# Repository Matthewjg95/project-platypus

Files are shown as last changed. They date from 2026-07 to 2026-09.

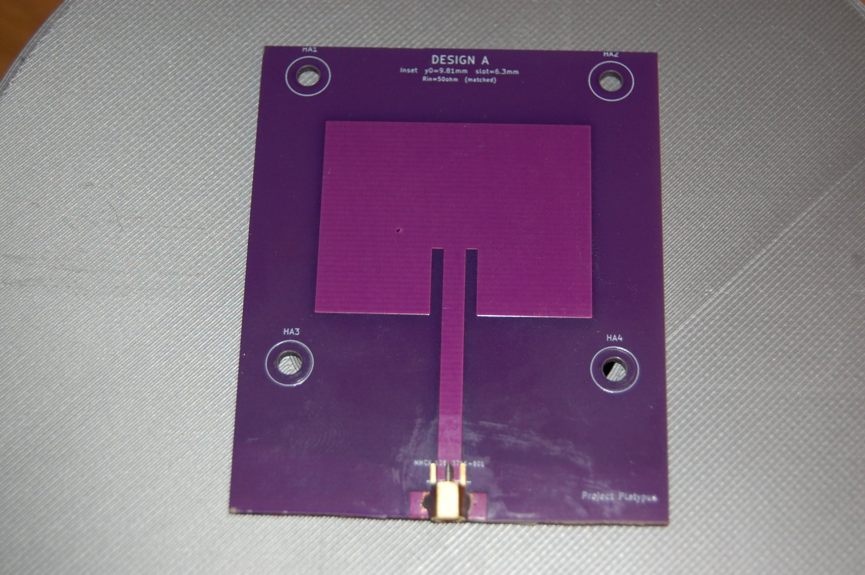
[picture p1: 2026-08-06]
assets/photos/p01_antenna_pcb_designA.jpg

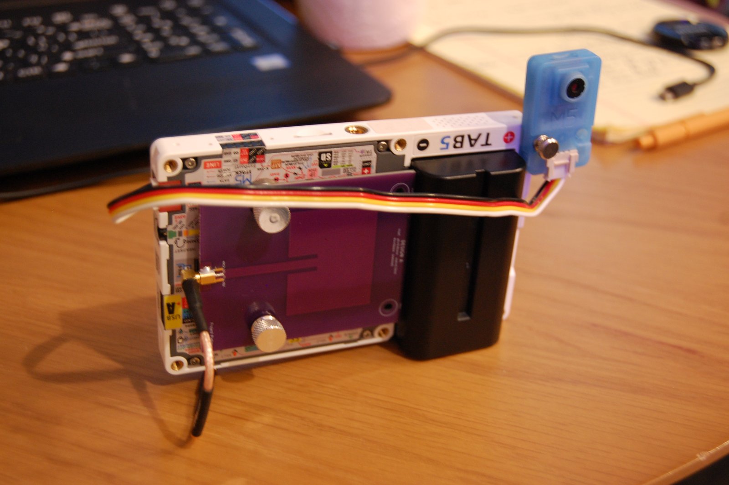
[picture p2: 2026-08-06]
assets/photos/p10_assembled_rig.jpg

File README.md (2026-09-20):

# Project Platypus 🦫

**A self-mapping RF instrument.** An M5Stack **Tab5** with a tethered AI
camera scans a room into a floor plan — then measures the WiFi and paints the
signal onto the map it just drew, one heat layer per antenna, including a
custom patch antenna PCB. No imported floor plans anywhere in the loop: the
instrument draws its own.

> **Status (Sep 2026): submitted to the M5Stack Global Innovation Contest 2026 —
> not selected. This repository is the frozen submission snapshot and is
> archived. Development continues in the lab repo (`platypus-lab`, private),
> which carries the full applet set including ShadowScan.**

Built for the **M5Stack Global Innovation Contest 2026**, as an exercise in
pushing the Tab5 (ESP32-P4) and friends to their limits — and, at roughly
$130 of parts, an accidental RF classroom: aim the patch antenna and watch
directionality appear on the map; swap in an antenna you made and the
instrument tells you if it's better. (The custom antenna boards were $40
for a panel of 45 — the antenna is literally the cheapest part of the
instrument that measures it.)

```
┌─────────────────────────────  M5View shell  ─────────────────────────────┐
│  3D Viewer          Room Scan                    Antenna                 │
│  .mesh renderer     UnitV camera → YOLO →        2.4GHz RSSI scope,      │
│  (orbit/zoom)       carved floor plans,          channel scan, polar     │
│                     WALK+ scans, building map,   plot, INT/EXT switch    │
│                     RF heatmap surveys                                   │
└──────────────────────────────────────────────────────────────────────────┘
        Tab5: ESP32-P4 @360MHz, 1280x720 touch, BMI270 IMU, ESP32-C6 WiFi
        UnitV: Kendryte K210 (KPU NPU), OV7740, MaixPy — tethered via Grove UART
```

## What it does

- **Sweep scan** — stand in a corner, sweep 360°. The BMI270 gyro measures
  the turn (stillness-locked bias calibration, gravity-projected so grip
  doesn't matter); a **sweep dial** fills as you rotate, dropping a colored
  pip at the bearing of every object the camera confirms, and the scan
  finishes itself at a measured full turn. The tethered UnitV streams JPEG +
  YOLOv2 detections over 460800-baud UART; objects are ranged monocularly
  from known real-world sizes (width preferred for wide furniture), passed
  through box sanity gates, and placed by the **median** of their sightings.
- **Visibility-carved floors** — no wall sensor, so the floor is built from
  evidence: where you stood, everything you saw (each sight-line proves open
  floor between you and the object), and everywhere you walked. Rooms come
  out L-shaped when they are L-shaped — not bounding boxes.
- **WALK+** — extend a scanned room on foot. IMU step detection dead-reckons
  your path (drift absorbed by registering against the room's own objects as
  landmarks); the walked path becomes floor-truth for the carve, and —
- **Walk-fused RF survey** — while you walk, the target AP is sampled at
  your pose *and bearing*, so **one walk produces the room and its heatmap**.
  Manual tap-to-sample still works. Heat layers are per-antenna (internal vs
  the custom MMCX patch via the Tab5's RF switch), with a dBm legend and
  automatic DEAD / BEST spot callouts. Because every sample records its aim,
  the directional patch is measured honestly — and its strongest bearing
  draws an "AP this way?" ray. (Ekahau needs an imported floor plan;
  Platypus draws its own.)
- **Additive scanning** — rescanning registers new observations against the
  room's persistent object database (yaw + translation solved from the
  objects themselves) and merges. Rooms improve with every pass; a per-room
  **object menu** toggles anything the model found on/off, and the floor
  re-carves to match.
- **Building map** — every room's carved footprint on one top-down canvas;
  drag rooms to arrange your building, tap to open. Arrangements persist.
- **Live view** — realtime detection viewfinder with class-colored boxes.
- **3D Viewer** — the original mesh renderer (int16 vertices, precomputed
  normals, bucket-sorted painter's algorithm) for `.mesh` files from SD;
  `tools/stl_to_mesh.py` converts STLs.
- **Antenna** — 2.4GHz test bench: a live RSSI oscilloscope and a
  fast-sampling walk test, both driving the internal/external antenna
  switch, with per-antenna running averages and CSV logging to SD.

## Repo layout

```
Tab5 3D Render/          the Tab5 firmware (PlatformIO, Arduino, ESP32-P4)
  src/                   M5View shell + applets (viewer, scanner/, antenna/)
  src/scanner/cv/        portable SfM pipeline for Phase 2 (ORB, RANSAC,
                         essential matrix, triangulation, surface recon)
  docs/                  renderer internals, heatmap design, detection
                         tuning protocol, antenna/WiFi postmortem
  tools/                 stl_to_mesh, screenshots, OTA push, serial log
meshscan/
  unitv/                 UnitV (K210/MaixPy) camera firmware — deploys as a
                         single bundled boot.py
  tools/                 unitv_bundle, unitv_upload, mesh_to_obj, kmodel_info
  shared/                standalone .mesh format spec
docs/                    roadmap docs: ToF wall ranging, RF directionality,
                         custom detection model walkthrough
assets/                  build photos + device screenshots
```

## Building & flashing

**Start here: [docs/BUILD_GUIDE.md](docs/BUILD_GUIDE.md)** — desktop
prerequisites → assembly → camera flash → Tab5 flash → first scan, with a
troubleshooting table. **[docs/CODE_TOUR.md](docs/CODE_TOUR.md)** is a
guided reading order for the source. The short version:

**Tab5** (PlatformIO):
```bash
cd "Tab5 3D Render"
pio run -e tab5 -t upload                 # over USB
pwsh tools/ota_push.ps1                   # over WiFi (device on home screen)
```
- Create `Tab5 3D Render/include/wifi_creds.h` (gitignored) with
  `OTA_WIFI_SSID / OTA_WIFI_PASS / OTA_HOSTNAME` before building.
- OTA arms only on the M5View home screen (green `OTA ready` chip), so it
  never fights the applets that own the radio. 60s watchdog + serial
  heartbeat built in.

**UnitV camera** (MaixPy v0.5.0 on the K210):
```bash
cd meshscan/tools
python unitv_bundle.py                    # bundles modules into one boot.py
python unitv_upload.py ../unitv/build/boot.py /flash/boot.py COM10
```
- The bundle exec-loads every module from RAM at boot (this MaixPy build's
  boot-time filesystem imports are unreliable) and sidesteps SD shadowing.
- Detection model: tiny-YOLOv2 VOC-20 (`meshscan/unitv/model/20class.kmodel`,
  from kendryte-standalone-demo) goes on the camera SD as
  `/sd/20class.kmodel`.

**Debug niceties**
- `python "Tab5 3D Render/tools/tab5_screenshot.py" COM6 out.bmp` — send
  `SS` over USB, get a pixel-perfect 1280x720 framebuffer capture.
- `tools/serial_log.py` — timed telemetry capture (it localized an
  intermittent camera freeze to corrupt bytes arriving on the link — frames
  stalled while CRC errors climbed, receiver healthy throughout, resync
  self-recovering within seconds).
- Serial heartbeat `[hb] up/home/ota/heap` every 5s pinpoints any lockup.

## Hard-won hardware notes (the short list)

- **Tab5 WiFi**: the P4 has no radio — WiFi rides an ESP32-C6 over hosted
  SDIO. Arduino defaults target the P4 EV-board; the Tab5 needs
  `WiFi.setPins(12, 13, 11, 10, 9, 8, 15)` *before* any WiFi call.
- **ArduinoOTA/mDNS must init at most once per boot** on hosted WiFi —
  an end()/begin() cycle hard-froze the loop task.
- **UART RX buffer**: `setRxBufferSize()` is a no-op *after* `begin()`.
  Real-room JPEGs (~8KB) overflowed the default buffer → CRC storm. 32KB,
  set before begin.
- **PI4IOE5V6408 expander (RF switch, 0x43)**: register 0x01 is *Chip
  ID/Control with bit0 = software reset* — writing it blanks the display
  (other rails share the chip). Output register is 0x05; Hi-Z (0x07) must be
  cleared to drive a pin.
- **K210/MaixPy**: `/sd` precedes `/flash` in sys.path (stale SD files shadow
  firmware); boot-time file opens fail intermittently on some files; ampy
  crawls at ~1KB/s — hence the bundler + custom uploader.
- **A directional antenna breaks position-only surveys**: patch RSSI is a
  function of position AND aim (10–15dB front-to-back), so every sample
  records its bearing — omni layers ignore it, the patch layer requires it.

## Roadmap

Measured wall polygons via a ToF ranger on the M5-Bus I2C (the sweep dial
becomes a live floor-plan radar — see `docs/TOF_RANGING.md`), a custom
detection model with door/window classes (`docs/CUSTOM_MODEL_WALKTHROUGH.md`),
Phase-2 SfM walls, an M5-Bus expansion breakout PCB ("Design B": one small
board fans the internal I2C out to Grove jacks — ToF at 0x29, the joystick
at 0x63 whose driver already waits in-tree, and friends), and a printed
enclosure with a peripheral bay + swappable sensor pod to house it all.

---
*Built collaboratively with Claude (Anthropic) driving firmware, debugging,
and tooling over serial — including taking its own screenshots of the device.*

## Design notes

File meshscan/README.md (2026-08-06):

# meshscan/ — UnitV camera firmware + desktop tools

The camera half of Project Platypus. The Tab5 firmware lives in
`Tab5 3D Render/`; this tree holds what runs on the **M5 Unit V (Kendryte
K210)** and the desktop helpers that deploy and inspect it.

| Path | What |
|---|---|
| `unitv/` | MaixPy firmware: OV7740 capture → KPU tiny-YOLOv2 → JPEG + detections streamed over Grove UART (460800) as framed, CRC-8-checked packets |
| `unitv/model/20class.kmodel` | tiny-YOLOv2 VOC-20 (kendryte-standalone-demo), lives on the camera SD as `/sd/20class.kmodel` |
| `tools/unitv_bundle.py` | bundles every module into ONE `boot.py` executed from RAM — this MaixPy build's boot-time filesystem imports are unreliable, and a single file also sidesteps `/sd` shadowing `/flash` |
| `tools/unitv_upload.py` | chunked base64 raw-REPL uploader (ampy crawls and mis-roots relative paths) |
| `tools/unitv_fix_sd_shadow.py` | removes stale SD copies that would shadow flash modules |
| `tools/mesh_to_obj.py`, `tools/kmodel_info.py` | inspect scan output / kmodel headers on the desktop |
| `shared/mesh_format.h` | standalone spec of the `.mesh` binary format |

## Deploy the camera

```bash
cd meshscan/tools
python unitv_bundle.py                                   # -> ../unitv/build/boot.py
python unitv_upload.py ../unitv/build/boot.py /flash/boot.py COM10
```

Wire protocol (camera → Tab5): `FRAME 0xF1 | len u16 | jpeg | crc8` and
`DETECT 0xD1 | frame_id u16 | count u8 | 10B/det | crc8` (CRC-8 poly 0x07).
Config (baud, model path, anchors, thresholds, detect-every-N) lives in
`unitv/config.py`; the camera prints `[det]`/`[tele]` telemetry on its USB
console while the Grove feeds the Tab5.

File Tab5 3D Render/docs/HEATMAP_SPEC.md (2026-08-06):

# RF Survey — WiFi Heatmap on a Self-Scanned Room

> **STATUS: historical design document.** The survey shipped, evolved past
> this spec, and `src/scanner/rf_survey.h/.cpp` is the source of truth. What
> changed since this was written: samples live in the mesh's **int16 model
> space** with the capture quantisation recorded so rebuilds remap them
> (format **RFS4**); every sample records the device **bearing** (the
> external patch antenna's RSSI depends on aim as much as position); INT/EXT
> antennas are separate flippable heat layers with DEAD/BEST callouts and a
> legend; the AP picker is a real UI with a persisted global choice; and
> **WALK+ fuses surveying into walking** — pose-tracked samples collect
> automatically during a walk scan. Kept for the original design rationale.

The Project Platypus fusion feature and contest centerpiece: scan a room into a
3D mesh (Room Scan), then walk the room sampling WiFi RSSI and paint the signal
onto the mesh you just made. Ekahau needs an imported floor plan; Platypus
draws its own.

**MVP = manual sampling** (user taps their position). SfM pose-tracked
auto-positioning is the roadmap version, not the contest version.

---

## 1. User flow (the contest demo path)

```
BROWSE room list ──open──> VIEW (3D mesh)
                              │  new [SURVEY] button
                              v
                           SURVEY
   ┌───────────────────────────────────────────────┐
   │  left 2/3: TOP-DOWN floor plan of the mesh    │
   │    (room footprint + object markers + past    │
   │     samples as colored discs)                 │
   │  right 1/3: live RSSI readout (big number),   │
   │    AP name, antenna INT/EXT toggle,           │
   │    [SAMPLE HERE] button                       │
   └───────────────────────────────────────────────┘
1. First entry: pick target AP (reuse antenna app's scan-and-pick list).
2. Walk somewhere. Tap your location on the floor plan -> crosshair.
3. Press SAMPLE -> 3 quick single-channel scans, averaged -> disc appears,
   colored by dBm. Auto-saves.
4. 8-12 samples in, toggle [HEAT] -> IDW-interpolated floor heatmap renders
   (2D top-down first; 3D floor painting once renderer supports face colors).
5. Optional wow: switch INT->EXT antenna, resample same spots -> two layers,
   compare internal vs MMCX antenna coverage on the same map.
```

Back button: SURVEY -> VIEW -> BROWSE (existing pattern, reset touch state).

## 2. Data model

```cpp
// One measurement at a user-declared position (room/mesh coordinates, metres,
// same frame as the .mesh: floor plane XZ, origin = scan origin).
struct RfSample {
    float   x, z;          // position on floor plane
    int8_t  rssi;          // averaged dBm of the sample burst
    int8_t  rssi_min, rssi_max;
    uint8_t antenna;       // 0=INT 1=EXT
    uint8_t flags;         // reserved
    uint32_t t_ms;         // millis() at capture (session-relative)
};

struct RfSurvey {
    char     ssid[33];
    uint8_t  bssid[6];
    uint8_t  channel;
    uint16_t count;
    RfSample samples[RF_MAX_SAMPLES];   // 256 is plenty; 3.5 KB
};
```

### On-disk: `<room>.rf` next to `<room>.mesh`
`/meshscan/buildings/<b>/<room>.rf`, little-endian:

```
magic  "RFS1"            4 bytes
ssid   char[33]          NUL-padded
bssid  u8[6]
chan   u8
count  u16
samples: count * 16 bytes  (f32 x, f32 z, i8 rssi, i8 min, i8 max,
                            u8 antenna, u8 flags, u8 pad, u16 pad)
```

Load on entering SURVEY if present; append + rewrite on each sample (file is
tiny, no chunking needed). Delete room -> delete .rf too (project_manager).

## 3. WiFi sampling (scanner side)

Reuse the antenna app's proven recipe, minimally:

```cpp
WiFi.setPins(12, 13, 11, 10, 9, 8, 15);   // Tab5 C6 - once, before mode()
WiFi.mode(WIFI_STA);
// AP pick: full scanNetworks() once, user taps AP (strongest preselected).
// Per sample: 3x single-channel scan (WiFi.scanNetworks(false,false,false,
// SCAN_DWELL, channel)), match BSSID, average RSSI. ~300-500 ms total.
```

- Sampling happens ONLY in SURVEY state (no background scanning; UART/scan
  pipeline untouched).
- INT/EXT toggle drives the RF switch exactly as the antenna applet does
  (`M5.In_I2C` expander write, 1 s settle before sampling).
- Coexistence note: WiFi (C6 SDIO) + SD + UART camera feed have all run
  together already; survey does not use the camera, so no new contention.

## 4. Rendering

### 4a. Top-down floor plan (MVP, pure 2D — ships first)
- Orthographic projection of mesh bounds onto XZ: `px = (x-xmin)/(xmax-xmin)*W`.
- Draw: room rectangle, object markers (from scan's acc list / .mesh objects)
  as small labeled squares, samples as filled discs (r=8) in the dBm color.
- Crosshair at pending tap position.

### 4b. Color scale (shared)
```
>= -55 dBm  green   0x07E0      -70..-80  orange  0xFC00
 -55..-70   yellow  0xFFE0      < -80     red     0xF800
no data     dark grey grid
```

### 4c. Heatmap interpolation (MVP)
Inverse-distance weighting over a coarse floor grid:
- Grid: 32 x 24 cells over mesh XZ bounds (fits any room aspect).
- `value(cell) = sum(w_i * rssi_i) / sum(w_i)`, `w_i = 1/(d_i^2 + eps)`;
  cells farther than ~2.5 m from every sample render as "no data".
- 32*24*~10 samples = trivial compute; recompute on each new sample.
- 2D view: fillRect per cell at 60% opacity feel (blend by drawing the grid
  first, discs/objects on top).

### 4d. 3D floor painting (stretch, after 2D works)
One contained renderer extension unlocks this AND Phase-2 colored geometry:

```cpp
struct Mesh {
    ...
    uint16_t* face_colors = nullptr;   // optional; RGB565 per face
};
// renderer.h: color = mesh.face_colors ? tint(face_colors[i], shade)
//                                      : _shade_color(rn);
```

Then SURVEY builds a floor-grid sub-mesh (2 triangles per cell, y=0.01) with
`face_colors` from the IDW grid and appends it to the room mesh for the 3D
view. Billboard-free, no new draw path.

## 5. Code layout

```
src/scanner/rf_survey.h/.cpp   RfSurvey store, .rf IO, IDW grid, color scale
src/scanner/scanner_applet.h   + SURVEY state: touch handling, 2D draw,
                               sample flow, AP picker (modeled on antenna's)
src/renderer.h                 + optional face_colors (stretch item 4d)
```

Keep rf_survey.* free of display calls (testable), scanner_applet owns UI —
same split as the rest of the scanner.

## 6. Effort plan

| Step | Scope | Est |
|---|---|-----|
| 1 | rf_survey store + .rf IO + color scale | 0.5 d |
| 2 | SURVEY state: top-down view, tap, crosshair | 1 d |
| 3 | WiFi sample burst + AP picker | 0.5 d |
| 4 | IDW grid + 2D heat overlay | 0.5 d |
| 5 | INT/EXT dual-layer surveys | 0.5 d |
| 6 | (stretch) face_colors renderer + 3D floor paint | 1 d |

MVP (1-5) ≈ 3 days of focused work; contest-demoable after step 4.

## 7. Roadmap (post-contest)
- SfM pose-tracked sampling: Phase-2 pipeline already estimates camera pose;
  tag RSSI to live pose while walking -> dense heatmap, no tapping.
- Multi-AP surveys (store N surveys per room, switch layers).
- Channel-congestion overlay (antenna app's channel scanner data on the map).
- Export: .rf -> CSV/PNG via a desktop tool in meshscan/tools/.
```

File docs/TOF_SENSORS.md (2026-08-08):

# Time-of-Flight Sensors — How They Actually Work

Research companion to `TOF_RANGING.md` (which covers our integration plan).
This is the physics and engineering background for the VL53L1X that's about
to join the instrument — what it measures, how, and where it lies.

---

## 1. The core idea, and why it's hard

Light travels ~30cm per nanosecond. Measure how long a photon takes to fly
to a wall and back, halve it, multiply by c: that's your distance. The
problem is the timescale — a millimetre of range resolution corresponds to
**~6.7 picoseconds** of round-trip time. No $5 chip times a single photon
that precisely. Every practical ToF sensor is a clever workaround for that
fact, and the workarounds split into two families.

## 2. Direct ToF (dToF) — what the VL53 family is

Direct ToF really does time photon flights — it just does it *statistically*.

1. A **VCSEL** (vertical-cavity surface-emitting laser, 940nm, Class 1
   eye-safe) fires thousands of sub-nanosecond pulses.
2. The receiver is a **SPAD array** (single-photon avalanche diodes) —
   pixels so sensitive that ONE returning photon triggers a detectable
   avalanche. The VL53L1X has a 16×16 SPAD array behind a lens.
3. Each detection is time-stamped by a TDC (time-to-digital converter) and
   dropped into a **histogram** of arrival times.
4. After thousands of pulses, the histogram shows a peak: ambient photons
   arrive uniformly at random (a flat floor), while photons that bounced
   off your wall pile up at one specific round-trip time. Find the peak,
   read the distance.

This histogram trick is why dToF has properties that matter for us:

- **Range accuracy is mostly independent of target brightness.** A dark
  wall returns fewer photons → shorter max range and a noisier peak, but
  the peak's *position* (= distance) doesn't shift. Intensity-based sensors
  can't say that.
- **Ambient light raises the histogram's noise floor** rather than biasing
  the answer — sunlight (which contains plenty of 940nm) shortens usable
  range but degrades gracefully.
- **Multiple returns are visible in principle** — glass edge + wall behind
  it produce two peaks. (The VL53L1X reports the strongest; fancier lidars
  report several.)

## 3. Indirect ToF (iToF) — the other family, for contrast

Instead of pulses, iToF emits **continuously modulated** light (tens of
MHz) and measures the **phase shift** between emitted and received
waveforms — phase maps to distance. It's how most depth *cameras* work
(phone depth sensors, Kinect-era devices): cheap per-pixel, whole images at
once. The catch: phase wraps around every c/(2·f_mod) metres, creating
distance ambiguity that needs multi-frequency tricks, and accuracy depends
on signal strength. For single-point ranging, dToF won this market — which
is why the part we're using is dToF.

## 4. The VL53L1X specifically

| Property | Value | What it means for Platypus |
|---|---|---|
| Principle | dToF, SPAD histogram | reflectance-tolerant wall ranges |
| Emitter | 940nm VCSEL, Class 1 | invisible, eye-safe, indoor-friendly |
| Max range | ~4m (long mode, low ambient) | covers a room from its centre |
| Min range | ~4cm | never an issue for walls |
| FoV | ~27° cone, lens-defined | see §5 — the big caveat |
| ROI | programmable 4×4…16×16 SPADs | narrows FoV to ~15°, steerable! |
| Timing budget | 20–1000ms per reading | precision/speed dial (§6) |
| Distance modes | short / medium / long | short = best ambient immunity, ~1.3m cap |
| Typical σ | mm-level near, cm-level far | good enough to beat our carve cells |
| Interface | I2C @ 0x29, interrupt pin | rides the Tab5's M5-Bus internal I2C |

The **ROI feature deserves attention**: you can tell the chip which SPAD
sub-array to use, which both narrows the cone *and steers it slightly*
(±~5°) without moving anything. A future trick: three interleaved ROIs
(left/centre/right) per bearing = a crude 3-zone scanning lidar from one
static part.

## 5. Failure modes — where ToF lies to you

Ranked by how much each will bite the wall-ranging use case:

1. **The cone problem (biggest).** 27° at 3m is a ~1.4m-wide footprint.
   The sensor reports (roughly) the nearest strong return in that cone —
   a chair 1m away wins over the wall 3m away. Mitigations: narrow ROI,
   mount high aiming slightly up (over furniture), and fuse with the
   camera's object map (we KNOW where the chair is — reject ranges that
   match known objects and keep the far return for walls).
2. **Specular surfaces.** A glossy wall, window, or mirror at a non-normal
   angle reflects the beam *away* — few photons return; you get max-range
   noise or a wrong bounce path (mirror shows the reflected room!). Matte
   drywall is ideal; glass walls will be our enemy. Detectable partially
   via signal-rate + range-status flags.
3. **Dark absorptive targets.** Black felt curtains at 4m may simply not
   return enough photons in long mode. Shows up as status "signal fail" —
   filterable.
4. **Ambient IR.** Direct sunlight through a window floods 940nm.
   Short-distance mode is the most immune; expect degraded range near
   bright windows, fine everywhere else indoors.
5. **Crosstalk / cover glass.** Photons bouncing off a window in front of
   the sensor create a false near peak. ST provides a crosstalk
   calibration; our enclosure should leave the sensor aperture OPEN or use
   the calibration if we glaze it.
6. **Wraparound.** Beyond-max-range targets can alias into short readings
   (status flag 7). Filter by status, always.

**The golden rule: never use a bare distance.** The chip reports range
status and signal/sigma estimates with every reading — a trustworthy
pipeline filters on status==0 and feeds sigma into the per-bin median we
already planned (TOF_RANGING.md).

## 6. The precision/speed dial

Timing budget = how long the chip accumulates histogram photons:

- 20ms budget → ~±5mm σ short range, weaker at distance, 50Hz possible
- 33–50ms → the sweet spot for a sweeping scan: 20–30Hz, cm-class at 3m
- 200ms+ → mm-class but far too slow for a rotating sweep

Our sweep math (TOF_RANGING.md): even 20Hz gives a reading every ~0.5° of
rotation — 72 five-degree wall bins get ~10 readings each for medians.
Plan: **medium distance mode, 33ms budget, ~25Hz**, ROI narrowed to
~15–20°, status-filtered, per-bin median. Revisit after bench tests.

## 7. Why ToF beats the alternatives for this job

| Tech | Why not |
|---|---|
| Ultrasonic (HC-SR04) | huge beam lobe (~30°+), slow (~50ms of sound flight), echo multipath in corners, cm accuracy at best |
| IR triangulation (Sharp GP2Y) | ~1.5m max, analog drift, beam still wide |
| Spinning lidar (RPLIDAR etc.) | actually ideal data — but $100+, large, a motor to power and mount; philosophically a different instrument |
| Stereo / structured light | serious compute + calibration; the P4 is busy |
| **dToF (VL53L1X)** | $9, 4m, mm–cm σ, I2C, no moving parts, and our sweep IS the scan motor — the user's rotation replaces the lidar spindle |

That last cell is the design insight: a spinning lidar is a ToF sensor
plus a motor. **Platypus already has the motor — it's the person.** The
sweep dial turns a $9 static ranger into a polar scanner.

## 8. What this means for the firmware (when the part arrives)

1. `tof_ranger.h` — init (distance mode, budget, ROI), poll, and a
   `Reading { mm, sigma_mm, status }` struct. Portable; nothing but I2C.
2. Scan loop: tag readings with IMU yaw; keep status==0; 72-bin medians.
3. **Fusion pass**: reject wall candidates that coincide with known camera
   objects (the cone problem, solved by the sensor we already have).
4. `.wall` sidecar + carve upgrade: measured polygon replaces/augments the
   visibility carve; sight-line evidence still fills where ToF was blocked.
5. Sweep dial: draw the wall trace live — the dial becomes a radar.

---
*Sources: ST VL53L1X datasheet & UM2356 API docs, ST FlightSense appnotes
(histogram dToF architecture), general SPAD/TDC literature. Bench-verify
timing-budget/σ numbers on our unit before trusting them in the pipeline.*

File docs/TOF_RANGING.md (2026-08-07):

# ToF Wall Ranging — Research & Integration Plan

> **STATUS (2026-08-01): post-contest revision.** ToF hardware + custom
> enclosure are roadmapped for after the Aug 7 contest deadline. Until then
> the camera-only path carries layout: visibility-carved floors (occupancy
> union of origin + objects + sight-lines) replaced the rectangular plate.

**Goal:** during the same 360° sweep-dial scan, sample a real distance at every
bearing → the scan produces the room's **actual measured wall outline** (a polar
polygon) instead of a bounding plate inferred from object extents. Objects from
the camera land inside it; the RF heatmap paints onto true room geometry.

This is the single biggest layout upgrade available: rotation-only sweeps give
the camera zero parallax (no depth from motion is possible), and the K210 only
emits 2D boxes — but a ToF ranger measures distance directly.

---

## Hardware findings (researched 2026-08-01)

### The bus problem is solved — no Grove conflict

The Unit V camera owns the Grove port's pins (G53/G54) as UART, and the U006
hub is a passive splitter — UART + I2C can never share those pins. But the
Tab5's **M5-Bus 30-pin header exposes the internal I2C bus directly**:

| M5-Bus pin | Signal |
|---|---|
| SDA | **G31** |
| SCL | **G32** |
| 5V / 3V3 / GND | power |

G31/G32 is the same bus as the BMI270 IMU, RTC, touch, audio codec, and the
PI4IOE5V6408 expanders (0x43/0x44) — i.e. **`M5.In_I2C`, the exact API the
antenna applet already uses**. Proven code path, zero new drivers to bring up.

Address check — internal bus occupants: 0x10, 0x14/0x55, 0x32, 0x40, 0x41,
0x43, 0x44, 0x68. The ToF's **0x29 is free**. Traffic check: M5Unified
serializes In_I2C transactions; a 20–30 Hz ToF poll is light next to touch+IMU.

### Sensor choice

| Unit | Sensor | Range | Notes |
|---|---|---|---|
| **Unit ToF4M (recommended)** | VL53L1X | 4 mm – 4 m | ~30–50 ms/reading, I2C 0x29, ~27° FoV (narrowable to ~15° via ROI) |
| Unit ToF | VL53L0X | up to 2 m | cheaper, but 2 m is too short for wall ranging across a room |
| Mini ToF 90° | VL53L0CXV0DH | 2 m | right-angle form factor — interesting for the enclosure, same 2 m limit |

**ToF4M** it is: 4 m covers typical rooms from the center; 0x29 on In_I2C.

### Wiring

Grove pigtail (Grove-to-Dupont cable, ~$2) from the ToF4M onto the M5-Bus
header: 5V, GND, SDA→G31, SCL→G32. Grove I2C logic is 3.3 V — matches the
internal bus. The enclosure routes/strains this cable.

### BOM

- M5Stack Unit ToF4M (VL53L1X) — ~$9
- Grove-to-Dupont conversion cable — ~$2
- (already owned) Unit V camera on the Grove port, unchanged

---

## Sampling math — it fits the sweep perfectly

A sweep takes ~20–60 s over 360°. At a conservative 20 Hz ToF poll:

- 20–60 s × 20 Hz = **400–1200 range samples per sweep**
- one reading every **0.3–0.9° of rotation** — massively oversampled for a
  wall outline binned at 5° (72 bearings)

Pipeline per sweep: tag each reading with the IMU yaw at capture → bin into 72
bearings → **median per bin** (same robustness philosophy as object ranging) →
polar polygon.

Refinements after the raw polygon works:
1. Split-and-merge line fitting → straight wall segments from the polygon
2. Optional Manhattan snap (90° corners) using the Hough confidence we
   already compute in RoomFitter
3. Corner extraction → the "face a corner" origin convention becomes a
   *measured* anchor, which also gives rescan registration a hard landmark

The 27° sensor cone slightly rounds corners (reads the nearest surface in the
cone); VL53L1X ROI configuration can narrow it to ~15° if that matters.

### Portability note (standing principle)

The wall-ranging pipeline consumes `(yaw_rad, distance_m)` pairs — nothing
else. Any ranger (I2C ToF, UART lidar module, ultrasonic) that produces those
pairs slots in behind the same interface. Keep the sensor driver ~40 lines and
isolated in `src/scanner/tof_ranger.h`.

---

## Beyond the ToF: the M5-Bus as an expansion backbone

The ToF finding generalizes. The camera owns the Grove port's pins as UART —
but the M5-Bus header exposes the **internal I2C bus (SDA G31 / SCL G32)**,
and I2C is a *bus*: every additional I2C peripheral shares those two pins,
distinguished by address. Current occupants: 0x10, 0x14/0x55, 0x32, 0x40,
0x41, 0x43, 0x44, 0x68. That leaves room for:

| Peripheral | Address | Status |
|---|---|---|
| ToF ranger (VL53L1X) | 0x29 | free — this doc's plan |
| M5 Joystick unit | 0x63 | free — **the driver already sits in-tree**
  (`src/joystick_input.h`), disabled since the joystick was unplugged from
  the camera's UART pins; it wires straight back up here |
| Any Grove I2C unit (env sensors, encoders, …) | varies | check the map |

The M5-Bus also carries SPI, UART0, RS485, and ~13 free GPIOs for
peripherals that aren't I2C.

**The physical layer — "Design B":** Grove pigtails onto header pins work
for one device but not for a rig. The clean answer is a small custom
breakout PCB — M5-Bus header in, 3-4 Grove (HY2.0-4P) jacks out, all
sharing the internal I2C + power. The antenna fab run cost $40 for 45
boards; an expansion breakout is the same order of trivial. One board turns
the Tab5's back into a proper peripheral bay — which is exactly what the
enclosure below should assume.

## Enclosure (next phase)

Once camera + ToF + Tab5 travel together, a 3D-printed bracket becomes the
right move:

- **Rigid co-aim is the whole game:** ToF and camera optical axes parallel,
  both normal to the Tab5 back. A fixed yaw offset between them is fine —
  one constant in software — but it must not flex scan-to-scan.
- Back-shell clamshell around the Tab5 with a sensor pod top-center:
  Unit V + ToF4M side by side, Grove cable channel to the port, pigtail
  channel to the M5-Bus header (header access must stay open).
- Keep the power button, USB-C, speaker grille, and antenna connectors clear;
  leave the kickstand/hand-strap question for the design session.
- Stretch: the pod prints as a separate swappable module — future sensors
  (lidar, better camera) get a new pod, not a new shell. Matches the
  modularity principle.

---

## Integration order (when the ToF4M arrives)

1. `tof_ranger.h`: VL53L1X init + poll on `M5.In_I2C` (0x29), ~40 lines
2. Scan loop: sample (yaw, mm) at poll rate during SCAN; store 72-bin medians
3. `.wall` sidecar beside the mesh (bearing/distance table, "WAL1")
4. Mesh: replace the rectangular plate with the measured floor polygon +
   optional low wall ribs at the polygon edges
5. Sweep dial: draw the wall trace ON the ring as it's measured — the dial
   literally becomes a live floor-plan radar (contest demo gold)
6. RF survey: heatmap clipped/painted onto the measured polygon

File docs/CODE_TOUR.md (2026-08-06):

# Code Tour — a guided reading order

The codebase is written to be read: headers open with a purpose block
explaining *why* the module exists, and hard-won lessons are documented at
the line where they were learned (search the source for `HISTORY`,
`LIFECYCLE RULE`, `hard-learned`, `field report` — the comments carry the
war stories). This tour orders the reading so each file makes sense by the
time you reach it.

One honest caveat up front: most modules are small and single-purpose, but
`scanner_applet.h` is the orchestrator and it is *large* (~2,500 lines). It
is organized by scan-screen state; the section map below is your index into
it.

## The 30-second architecture

```
 Unit V camera (K210, MaixPy)                Tab5 (ESP32-P4, Arduino)
 ───────────────────────────                 ─────────────────────────────
 sensor → KPU YOLOv2 → JPEG      UART        UartReceiver → FrameBuffer
        (every Nth frame)      460800 baud            │
 FRAME / DETECT packets, CRC-8  ────────►    ScannerApplet (state machine)
                                             │  DepthEstimator   (range)
                                             │  RoomObjDB        (persist+register)
                                             │  PoseTracker      (walk pose)
                                             │  room_carve       (floor evidence)
                                             │  ScanGeometry     (triangles)
                                             │  ScanMeshWriter   (quantise+save)
                                             │  RfSurvey         (heatmap layers)
                                             ▼
                                    M5View shell ← Viewer / Antenna applets
```

## Reading order

### 1. The platform (20 minutes)

| File | What you learn |
|---|---|
| `src/applet.h` | The whole applet contract: enter/update/render/back/pause/resume. Everything else plugs into this. |
| `src/shell.h` | Tile launcher, settings panel, touch routing. Why open/close is instant (animation trails were a bug class). |
| `src/main.cpp` | Boot order, the home-screen-only OTA lifecycle (begin-once rule), watchdog, serial screenshot protocol. |

### 2. The renderer (30 minutes)

| File | What you learn |
|---|---|
| `src/mesh.h` | int16 quantised vertices + faces; the format everything downstream targets. |
| `src/mesh_loader.h` | SD → PSRAM streaming load. |
| `src/renderer.h` | Transform → backface cull → flat shade → painter's sort → rasterise. `docs/RENDERER_INTERNALS.md` goes deeper. |
| `src/viewer_applet.h` | The renderer wrapped as an applet; trackball math in `vm3.h`. |

### 3. The camera link (20 minutes)

| File | What you learn |
|---|---|
| `meshscan/unitv/config.py` | Every camera knob: baud, model path, anchors, threshold, cadence. |
| `meshscan/unitv/main.py` + `uart_protocol.py` | Capture loop and the FRAME/DETECT framing (CRC-8). |
| `src/scanner/uart_receiver.*` | The Tab5 end: resync state machine, CRC validation, the 32KB-before-begin RX buffer lesson. |
| `src/scanner/frame_buffer.*` | Slots pairing a JPEG with its detections by frame id. |

### 4. The scanning brain (1 hour, the good part)

Read the small pure-logic modules first — none of them knows M5 exists:

| File | What you learn |
|---|---|
| `src/scanner/depth_estimator.*` | Monocular ranging from known object sizes + the box sanity gates (min size, aspect, edge-clip, range ceiling). |
| `src/scanner/room_objdb.h` | The per-room object database; observation merging; **landmark registration** (yaw × same-class-pair search) that lets rescans align themselves. |
| `src/scanner/pose_tracker.h` | Step detection → dead-reckoned walk pose. Feed it accel magnitude + heading; nothing else. |
| `src/scanner/room_path.h` | The walked path sidecar (floor-truth evidence). |
| `src/scanner/room_carve.h` | The visibility carve: origin + sight-lines + paths stamped into an occupancy grid. Why rooms come out L-shaped. |
| `src/scanner/scan_geometry.*` | Occupancy grid → greedy-meshed floor + markers + origin arrow. |
| `src/scanner/scan_mesh_writer.*` | World metres → int16 quantisation (the Y-mirror and winding notes matter). |
| `src/scanner/rf_survey.*` | Survey samples with **bearing** + capture quantisation; IDW heat grid; why RFS4 remaps on rebuilds. |

Then the orchestrator, with this index:

**`src/scanner/scanner_applet.h` section map** (in file order):
- BROWSE — room list, scroll, long-press delete, the Scan/Live/Map buttons
- SCAN — sweep dial, stillness-locked bias calibration, IMU yaw
  integration, walk mode (pose tick + RF sampling), `_sample()` where
  detections become observations
- `_write_phase1` / `_rebuild_from_db` — where a scan becomes a mesh:
  registration → merge → carve → geometry → quantise → sidecars
- VIEW — orbit render, label billboards, OBJ menu (per-room object
  toggles), SCAN+/WALK+/RF buttons
- BUILDING MAP — footprint thumbnails, drag-to-arrange, persistence
- RF SURVEY — AP picker, sampling, heat layers, DEAD/BEST callouts,
  bearing readout
- LIVE — detection viewfinder

### 5. The antenna suite (optional, self-contained)

`src/antenna/antenna_applet.cpp` is a deliberately self-contained fullscreen
applet (scope/channel/polar/walk screens) — it predates the shell and shows
what "absorb an existing sketch as an applet" looks like. `src/rf_switch.h`
is the I2C expander driver with the register-0x01 warning.

### 6. Phase-2 scaffolding

`src/scanner/cv/` — a portable SfM pipeline (ORB → matching → essential
matrix/RANSAC → triangulation → surface) that compiles and runs but isn't
wired into the product yet. It exists so evidence-based walls have a
landing site; treat it as reference, not as load-bearing.

## Conventions worth knowing

- **Portable vs device code**: anything under `scanner/` that doesn't
  include M5Unified is hardware-agnostic by design — the swap-the-hardware
  principle is enforced at include level.
- **Sidecar files are versioned**: `.objs` (ROB2), `.path` (PTH1), `.rf`
  (RFS4), labels (LBL1) — every loader accepts its older versions.
- **Comments explain *why*, at the site of the lesson** — the UART buffer,
  the expander reset bit, the OTA begin-once rule, the bias stillness lock
  are all documented where they bit us.

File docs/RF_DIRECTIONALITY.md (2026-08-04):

# Directional Antenna & the RF Survey

## The problem (why the patch felt underused)

The survey stored each sample as `(x, z, rssi)` — RSSI as a **scalar field
over position**. That model is correct for an omnidirectional antenna and
**wrong for a patch**.

A patch antenna has a main lobe broadside to the board, roughly 6–8 dBi of
gain, and 10–15 dB of front-to-back rejection. So its RSSI is a function of
**position AND aim**. Two samples taken from the same spot facing different
directions can differ by more than the entire green-to-red span of the
heatmap legend — and the old code would average them into meaningless mush
via IDW.

Put bluntly: the patch layer wasn't just under-utilised, it was measuring
something that isn't a well-defined quantity. A judge who knows RF would
notice. Dropping the antenna would have been the wrong fix; measuring it
correctly is the right one.

## What shipped

1. **Every sample records its bearing.** `Sample.heading` — degrees, `0` =
   the mesh `+Z` axis (the direction faced at scan origin), `-1` = unknown.
   File format `RFS2` → `RFS3`; old files still load with heading unknown.
2. **Bearing comes from the IMU**, using the same gravity-projected gyro and
   stillness-locked bias as the scanner. The survey asks you to *face the
   START arrow and hold still* on entry — that single act ties the survey's
   heading frame to the room's frame.
3. **Aim ticks on the plan.** Each sample dot draws a whisker showing which
   way the device faced.
4. **Honest UI copy.** With the patch selected: *"patch: AIM AT AP before
   sampling."* With the internal antenna: *"omni: aim does not matter."*
   The measurement procedure is now part of the instrument.
5. **AP direction estimate.** A directional antenna reads strongest when
   aimed at the source, so the best EXT sample's own bearing estimates where
   the AP is — drawn as a cyan ray labelled *"AP this way?"*. Labelled as an
   estimate on purpose: indoor multipath makes it approximate.

The demo line this buys: *"the internal antenna measures coverage; the patch
measures reach in a direction — and it can point back at the router."*

---

## Walk-fused survey — SHIPPED

**The idea (Matt's):** WALK+ already tracks pose and heading while you walk
the room. Sample RSSI during that same walk and one pass produces the room
map *and* the survey — no tapping, dense coverage, every sample
heading-tagged for free. The antenna suite's scope screen already proves the
sampling cadence works while moving.

**Why it's the right end state:** it removes the survey's most tedious step
(tap position → tap sample, repeated), it collects far more points than
anyone would tap by hand, and it makes the patch's directionality a natural
product of walking rather than a separate procedure.

### Feasibility notes (checked)

- `_rf_measure()` uses `WiFi.scanNetworks(..., dwell=120, channel)` ×2 —
  ~250–400 ms blocking. The antenna suite uses `dwell=60` (~100 ms), which
  is the cadence to copy.
- A 100 ms block is **under** the scanner's `dt > 0.25 s` IMU guard, so yaw
  integration survives. Sample every ~1.5 s → ~7% duty cycle, safe for both
  the IMU and the 32 KB camera UART buffer.
- WiFi must be brought up inside the scanner (`_wifi_up()`), and a target AP
  must already be chosen (the global saved AP). No AP → skip silently.

### The coordinate problem (solved)

RF samples are stored in **quantised mesh space**, but during a walk the
final mesh doesn't exist yet — quantisation is computed at write time from
the finished geometry. And worse, a *pre-existing bug*: any rebuild that
changed the geometry bounds (hiding an object via the OBJ menu, a WALK+ that
grew the room) changed the quantisation, and existing samples — stored in
the *old* mesh space — silently slid relative to the new floor.

**Fix: `.rf` files now record the quantisation their samples were captured
under** (`qc[3]`, `qs`, format `RFS4`). On every rebuild the survey is
reloaded, `remap()`ed from the old quantisation to the new one, and saved.
The heatmap stays glued to the floor no matter how the room is edited. Files
without the field (`RFS2`/`RFS3`) load and adopt the current quantisation,
i.e. exactly today's behaviour, no worse.

That same machinery makes walk fusion trivial: walk samples buffer in world
metres and convert once, at the same moment.

### How it works now

- **Walk start:** if the room (or the saved global pick) has a target AP,
  WiFi comes up, the RF switch is set to the selected antenna, and the walk
  becomes a survey. No AP → skipped silently, walk behaves as before.
- **During the walk:** every 1.5 s, one single-channel scan at 60 ms dwell
  reads the target AP; the reading is buffered with the current pose and
  bearing. The mini-map drops a dot coloured by signal strength at each
  sample, so the heatmap visibly builds itself as you walk. The status line
  shows `Walk 12 st 8.4m | EXT RF:6 -58 dBm`.
- **At FINISH:** buffered samples convert world → mesh with the final
  quantisation and merge into the room's `.rf`, alongside anything sampled
  by hand.

### Demo consequence

The survey no longer requires tap-position-then-tap-sample. **One walk
produces the room and the heatmap together** — and because every sample
carries its bearing, the patch antenna's directionality is captured for
free. To survey with the patch: pick EXT in the RF screen once, then WALK+.

### Still worth doing later

- Choose the antenna directly from the walk screen (today it inherits the
  RF screen's selection — the HUD shows which, so it is unambiguous, just
  not adjustable in place).
- Multi-position bearing intersection for a true AP *fix* rather than a
  single-ray estimate.

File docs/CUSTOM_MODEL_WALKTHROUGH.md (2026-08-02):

# Custom Detection Model — Walkthrough (#1 roadmap item)

Replace the generic VOC-20 model (cats, bottles, 16-27% confidence) with a
room-mapping model trained on OUR classes. This is the single biggest
mapping-quality upgrade available with zero new hardware.

**Target classes (proposal, 10):** door, window, desk, monitor, chair, sofa,
bed, table, shelf, person. Doors and windows are the prize — they anchor
walls, doorway positions link rooms in the building map, and no amount of
tuning gets them out of VOC.

---

## Path A (recommended): MaixHub online training

MaixHub (maixhub.com, Sipeed's free training service) trains YOLO-family
detectors and exports **K210 kmodel V4** directly — the format our MaixPy
v0.5.0 firmware already runs. No local GPU, no nncase wrestling.

### 1. Collect the dataset — with the camera itself

The Unit V's own imaging quirks (lens, exposure, 320x240) should be IN the
training data. Two collection routes:

- **On-SD capture:** temporary MaixPy script that saves a JPEG to SD every
  2s while you slowly pan rooms. ~10 minutes per room gives hundreds of
  frames. (I can write `capture_dataset.py` for the Unit V when we start.)
- Phone photos work as filler but shift the domain; keep them a minority.

Guidelines:
- 150-300 images per class minimum, varied angles/lighting/distances
- Include NEGATIVES: frames with none of the classes (bare walls, floors)
- Capture at the camera's native aspect; MaixHub handles resize to 224x224

### 2. Label on MaixHub

Create a "Detection" project, upload, draw boxes in their web labeler (or
upload VOC/YOLO-format annotations if labeling locally in LabelImg).

### 3. Train + export

- Model type: YOLOv2 (K210-compatible backbone; MaixHub picks anchors)
- Export target: **K210 kmodel (V4)** — do NOT pick V5/K230 formats
- Download the bundle: `.kmodel` + generated anchors + class list

### 4. Deploy to the Unit V

1. Copy the kmodel to SD as `/sd/roomnet.kmodel` (the SD slot beats
   flashing it; our loader already prefers /sd)
2. Update `meshscan/unitv/config.py`:
   - `MODEL_PATH = "/sd/roomnet.kmodel"`
   - `ANCHORS = (...)` — the values MaixHub generated (5 pairs)
   - `CLASS_NAMES = (...)` — new class order, must match training exactly
   - `THRESHOLD` — start 0.30; custom models score far higher than the
     VOC-20's 16-27%, so the floor comes UP as quality goes up
3. Rebuild the bundled boot.py (`python meshscan/tools/unitv_bundle.py`)
   and push with `unitv_upload.py` (cable, dtr=False/rts=False)

### 5. Tab5-side changes (one file each)

- `object_labels.h/.cpp`: new class id -> name/colour table
- `depth_estimator.cpp`: new height/width tables — doors 2.03m tall(!),
  windows ~1.2m, desks 1.2-1.6m wide. Doors are a RANGING GIFT: nearly
  uniform height worldwide, tall (pixel-accurate), on every wall.
- `scanner_applet.h`: `_default_visible()` + `_acc_conf()`/`_min_obs()`
  per-class policies for the new ids
- Wire protocol, accumulation, carve, registration: **unchanged** — the
  architecture was built for this swap.

### 6. Validate (bench protocol)

Use the T1/T2 procedure in docs/DETECTION_TUNING.md: known objects at
measured distances, compare detected class + estimated range vs tape
measure. Tune per-class sizes from the errors.

---

## Path B: local training (fallback if MaixHub's free tier disappoints)

axelerate (Keras YOLOv2 for K210) or Sipeed's maix_train repo, then
`nncase 0.2.x` to compile to kmodel V4. Works but is a toolchain slog
(TF 1.x-era pins, nncase version sensitivity). Only if Path A dead-ends.

## Effort estimate

- Dataset capture+label: 2-4 hours (the slow part, mostly labeling)
- Training: ~1 hour on MaixHub's queue
- Deploy + Tab5 tables: ~1 hour
- Validation pass: 1 hour

Fits in a weekend; post-contest slot is fine, or pre-contest if a rainy
afternoon appears — the demo story gets much stronger with "door" and
"window" labels on the map.

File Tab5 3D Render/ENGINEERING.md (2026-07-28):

# M5Stack Tab5 — Portable 3D Mesh Viewer
## Engineering Reference

---

## Project Structure

```
m5viewer/
├── platformio.ini          — Build system config
├── src/
│   ├── main.cpp            — App entry point & render loop
│   ├── mesh.h              — Data structures (Vertex, Face, Mesh, RenderState)
│   ├── mesh_loader.h       — SD card binary .mesh loader
│   ├── renderer.h          — Full 3D pipeline (transform → cull → project → rasterise)
│   └── input.h             — Touch drag input handler
└── tools/
    └── stl_to_mesh.py      — Offline STL → .mesh converter
```

---

## Architecture Overview

```
[SD Card .mesh file]
        │
        ▼
  mesh_loader.cpp          — Parse header, alloc PSRAM, stream vertex+face data
        │
        ▼
     Mesh (PSRAM)           — Vertex[N] int16×3  +  Face[M] uint16×3
        │
        ▼
   renderer.cpp
        ├─ Build 3×3 rotation matrix  (once per frame)
        ├─ Transform all N vertices   (once per frame, O(N))
        ├─ For each face M:
        │    ├─ Backface cull (2D cross product)
        │    ├─ Compute flat-shaded colour
        │    └─ fillTriangle()  via M5GFX
        │
        ▼
  M5GFX display (batched via startWrite/endWrite)
```

---

## Module Reference

### mesh.h

Core data types.  Header-only, no allocation.

| Type | Size | Description |
|---|---|---|
| `Vertex` | 6 bytes | int16 x,y,z — quantised world position |
| `Face` | 6 bytes | uint16 a,b,c — vertex indices |
| `Mesh` | 24 bytes | Pointers + counts; data in PSRAM |
| `RenderState` | 24 bytes | Euler angles, scale, camera Z, FOV |
| `ProjectedVertex` | 12 bytes | float sx,sy,z — screen space result |

### mesh_loader.h

`bool load_mesh(const char* path, Mesh& mesh)`

- Opens SD file, reads 8-byte header (vertex_count, face_count).
- Allocates vertex buffer and face buffer in PSRAM
  (`MALLOC_CAP_SPIRAM`).
- Streams vertex block then face block directly into PSRAM buffers.
- Returns `false` on any error; prints diagnostics to Serial.

**Memory usage:**
```
vertex_count × 6 bytes   (e.g. 10000 verts = 60 KB)
face_count   × 6 bytes   (e.g. 15000 faces = 90 KB)
ProjectedVertex scratch  = vertex_count × 12 bytes = 120 KB
Total for 10k/15k mesh   ≈ 270 KB PSRAM
```

### renderer.h

**`bool begin(M5GFX* display, uint32_t max_vertices)`**
Allocates projected-vertex scratch buffer in PSRAM.

**`void render_frame(const Mesh&, const RenderState&, uint16_t bg)`**

Pipeline steps:

1. **Rotation matrix** — Euler Ry·Rx·Rz, computed once.
2. **Vertex transform** — All N vertices: rotate + perspective project → screen coords.  O(N).
3. **Clear screen** — `fillScreen(bg)`.
4. **Face loop** — O(M):
   - Backface cull: 2D cross product of screen-space edges.
     `cross = (B-A) × (C-A)`.  Skip if ≥ 0 (back-facing in Y-down coords).
   - Flat shade: compute face normal from camera-space edge vectors, dot with fixed light.
   - `fillTriangle(ax,ay, bx,by, cx,cy, color)`.
5. **Batch flush** — `startWrite()` / `endWrite()` wraps steps 3–4.

**Performance scaling (estimated):**

| Triangles | Expected FPS (ESP32-P4) |
|---|---|
| 5,000 | ~50 FPS |
| 10,000 | ~28 FPS |
| 15,000 | ~18 FPS |
| 20,000 | ~13 FPS |

Key bottleneck: `fillTriangle()` in M5GFX.  Each call involves SPI/parallel bus writes proportional to triangle screen area.

### input.h

`InputHandler::update()` → `InputDelta { dx, dy, active }`

- Polls `M5.Touch.getDetail()` each frame.
- Tracks previous touch position across frames.
- Applies 2-pixel deadzone to suppress jitter.
- Returns pixel deltas; caller multiplies by `DRAG_SENSITIVITY`
  (0.005 rad/px by default) to get rotation delta.

---

## .mesh File Format

```
Offset  Type      Description
------  --------  -----------
0       uint32    vertex_count
4       uint32    face_count
8       int16[3]  vertices[0]  — x, y, z
...     int16[3]  vertices[vertex_count-1]
8+6×vc  uint16[3] faces[0]    — a, b, c
...     uint16[3] faces[face_count-1]
```

All values little-endian.  No padding between records.

**File size formula:**
```
8  +  vertex_count × 6  +  face_count × 6   (bytes)
```

A 10k-vertex / 15k-face mesh = 8 + 60000 + 90000 = **150,008 bytes (~147 KB)**

---

## Python Converter — stl_to_mesh.py

### Installation

```bash
pip install numpy-stl        # required
pip install open3d           # optional: enables --decimate
```

### Usage

```bash
# Basic conversion
python stl_to_mesh.py part.stl part.mesh

# With in-script decimation (requires open3d)
python stl_to_mesh.py part.stl part.mesh --decimate 12000

# Inspect without writing
python stl_to_mesh.py part.stl part.mesh --info
```

### Pipeline steps

1. Load STL → merge duplicate vertices (numpy-stl).
2. Optionally decimate with open3d quadric simplification.
3. Centre bounding box at origin.
4. Scale longest axis to ±30000 int16 units.
5. Clip to int16 range, write header + vertex block + face block.

---

## Blender Workflow (Recommended)

For large or complex CAD parts, pre-process in Blender for best quality:

### Steps

1. **File → Import → STL** — import your CAD export.
2. Select the object.  In Properties → **Modifier** tab, add **Decimate**.
3. Set **Ratio** or switch to **Face Count** mode.
   - Target: 10,000–15,000 faces for 20–30 FPS.
4. Enable **Planar** mode and set **Angle Limit** to 5°–15° to preserve
   flat faces while decimating curved surfaces aggressively.
5. Click **Apply**.
6. **File → Export → STL (Binary)**.  ✓ Apply Modifiers.
7. Run `stl_to_mesh.py` on the exported file.

### Recommended Decimate settings

| Surface type | Ratio | Angle Limit |
|---|---|---|
| Mechanical (flat faces) | 0.1–0.3 | 5° |
| Organic / curved | 0.3–0.5 | 15° |
| Highly detailed | 0.05–0.1 | 3° |

---

## Performance Optimisation

### Implemented

| Technique | Where | Benefit |
|---|---|---|
| Transform once per frame | renderer.cpp | Eliminates N×M redundant transforms |
| int16 vertex storage | mesh.h | 2× smaller vertex data; better cache use |
| Backface culling | renderer.cpp | Skips ~50% of faces on convex meshes |
| PSRAM allocation | mesh_loader, renderer | Keeps internal SRAM free for stack |
| Display batching | renderer.cpp | Reduces SPI bus overhead |
| `-O2 -ffast-math` | platformio.ini | ~20–30% faster float math |

### Next optimisations (Phase 4)

1. **Z-sort faces** — Painter's algorithm; avoids intersecting
   triangles at low cost (~2 ms for 15k faces with radix sort).
2. **Tile-based rasteriser** — Split screen into 8×8 tiles; render
   only triangles overlapping each tile.  Reduces SPI transfer size.
3. **DMA-backed framebuffer** — Write pixel data off the CPU via DMA
   while the CPU processes the next batch of triangles.
4. **SIMD / fixed-point math** — ESP32-P4 supports vector
   instructions; replace float matrix multiply with fixed-point SIMD.
5. **Mesh bounding sphere cull** — Skip mesh entirely if off-screen.
6. **Face index sorting by depth** — Sort once on load; speeds up
   painter's algorithm to O(1) per frame for static camera changes.

---

## Debugging & Testing

### Serial diagnostics

Enable in `setup()`:
```cpp
Serial.begin(115200);
```

Renderer prints per-frame timing when HUD is active.
`load_mesh()` prints vertex/face counts and PSRAM usage on load.

### Frame time monitoring

The HUD overlay in `main.cpp` prints FPS and frame time every 500 ms.
Disable by commenting out the HUD block to remove `printf` overhead.

### Validating the .mesh file (Python)

```python
import struct, pathlib
data = pathlib.Path("part.mesh").read_bytes()
vc, fc = struct.unpack_from('<II', data, 0)
print(f"Vertices: {vc}  Faces: {fc}")
expected = 8 + vc*6 + fc*6
print(f"Expected size: {expected}  Actual: {len(data)}  {'OK' if len(data)==expected else 'MISMATCH'}")
```

### Common issues

| Symptom | Likely cause | Fix |
|---|---|---|
| Model invisible | Scale too small / cam_z too close | Increase `cam_z`; check `scale` |
| Inside-out normals | Winding order reversed in export | Flip normals in Blender or reverse face winding in converter |
| Corrupt triangles | Mesh not watertight after decimate | Use Blender "Fill Holes" before export |
| SD mount fails | CS pin wrong | Check `SD_CS_PIN` in platformio.ini |
| PSRAM alloc fails | Mesh too large | Decimate further; check `ESP.getFreePsram()` |
| Low FPS | Too many faces | Target ≤15k; enable `-O2 -ffast-math` |

---

## Development Phases

| Phase | Description | Status |
|---|---|---|
| 1 | Rotating hardcoded cube | ✅ Implemented |
| 2 | SD mesh loading | ✅ Implemented (toggle in main.cpp) |
| 3 | Touch rotation + zoom | ✅ Implemented |
| 4 | Z-sort, DMA, SIMD optimisation | 🔲 Planned |
| 5 | Lighting, Z-buffer, measurements | 🔲 Planned |
| 6 | Joystick navigation | 🔲 Designed (stub in input.h) |
| 7 | Vertex selection, annotations | 🔲 Future |

---

## Memory Budget (10k-vertex / 15k-face mesh)

| Region | Usage |
|---|---|
| Vertex PSRAM buffer | 60 KB |
| Face PSRAM buffer | 90 KB |
| ProjectedVertex scratch | 120 KB |
| M5GFX framebuffer (1280×720×2) | 1,843 KB |
| Firmware + stack + heap | ~512 KB |
| **Total PSRAM** | **~2.1 MB** |

ESP32-P4 has 8 MB PSRAM — comfortably within budget.

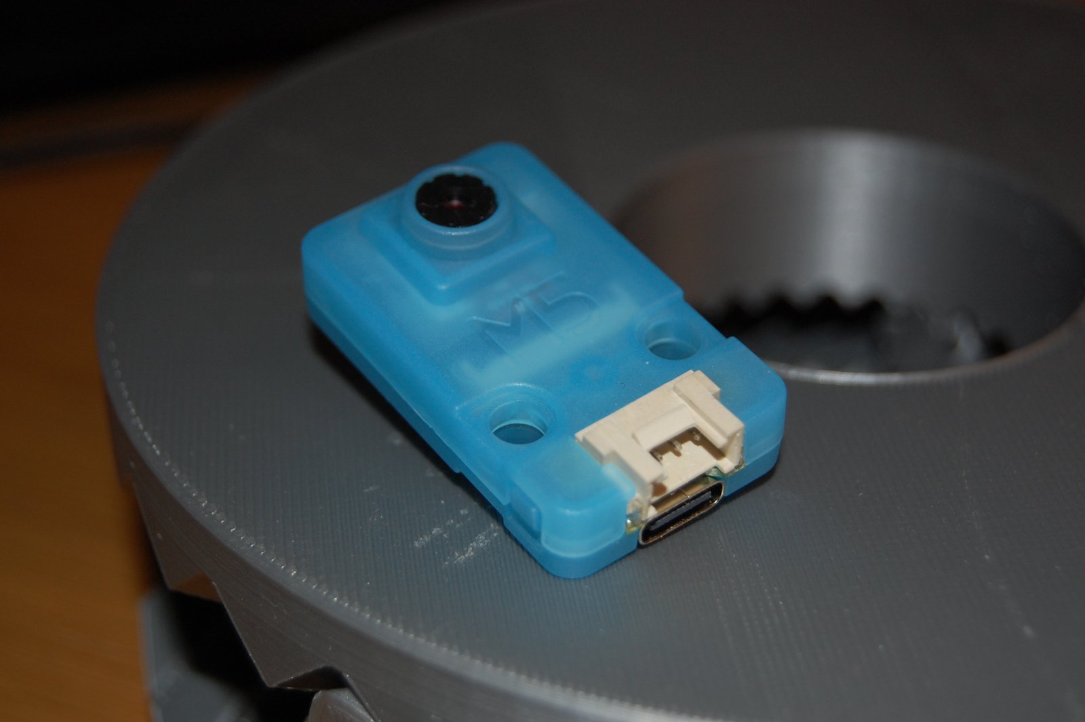
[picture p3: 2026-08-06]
assets/photos/p03_unitv_front.jpg

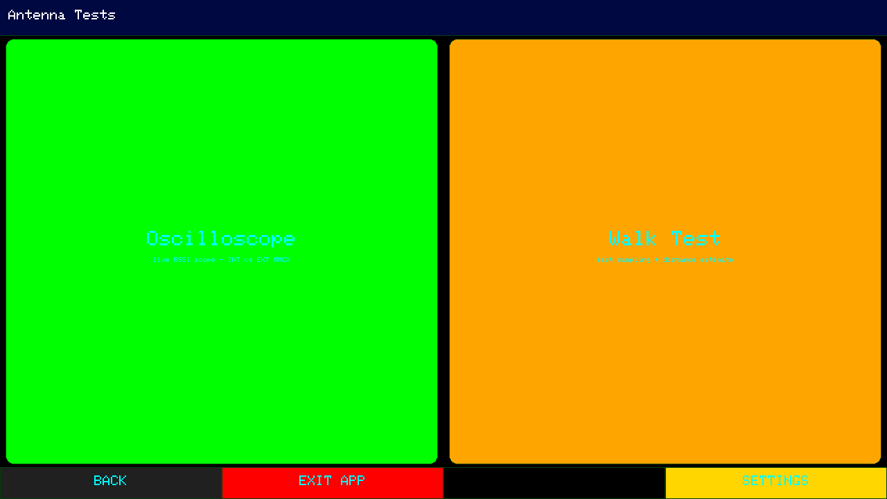
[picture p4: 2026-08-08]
assets/screens/s09_antenna_menu.png

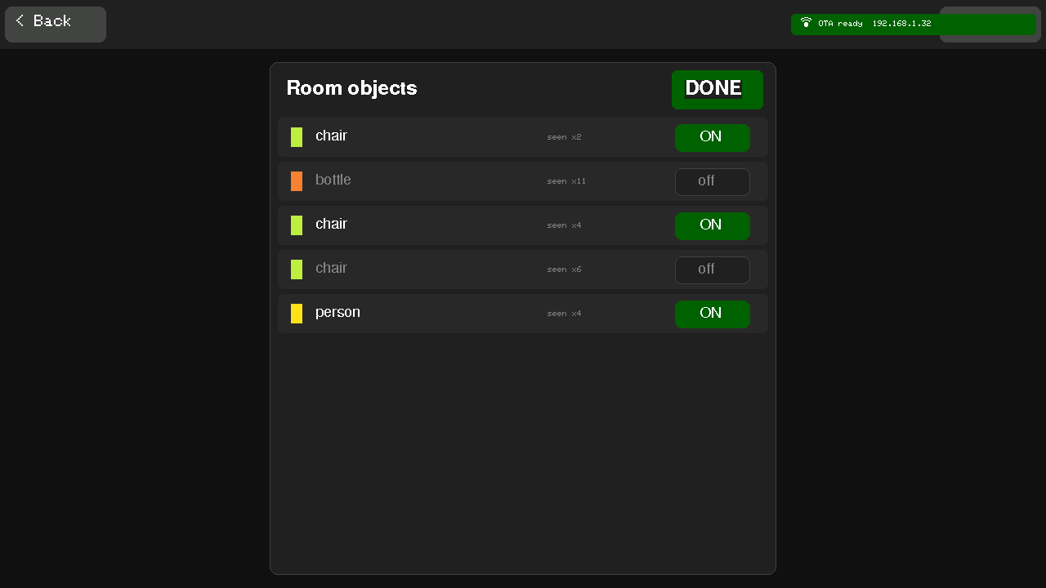
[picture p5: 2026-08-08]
assets/screens/s05_obj_menu.png

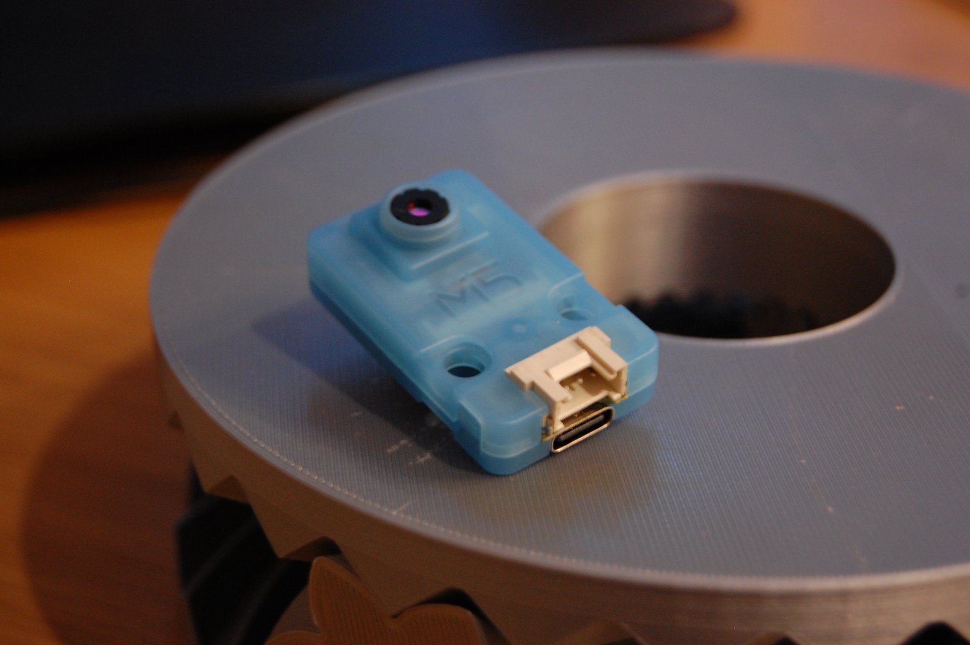
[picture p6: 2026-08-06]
assets/photos/p04_unitv_angle.jpg

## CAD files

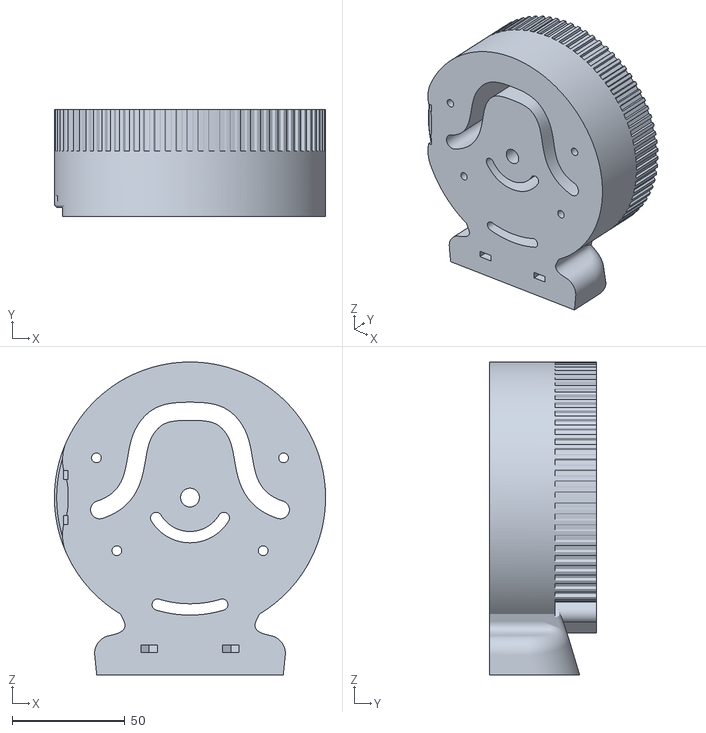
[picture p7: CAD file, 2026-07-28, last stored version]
Tab5 3D Render/input/2M2H.STL
120.0 x 47.5 x 138.5

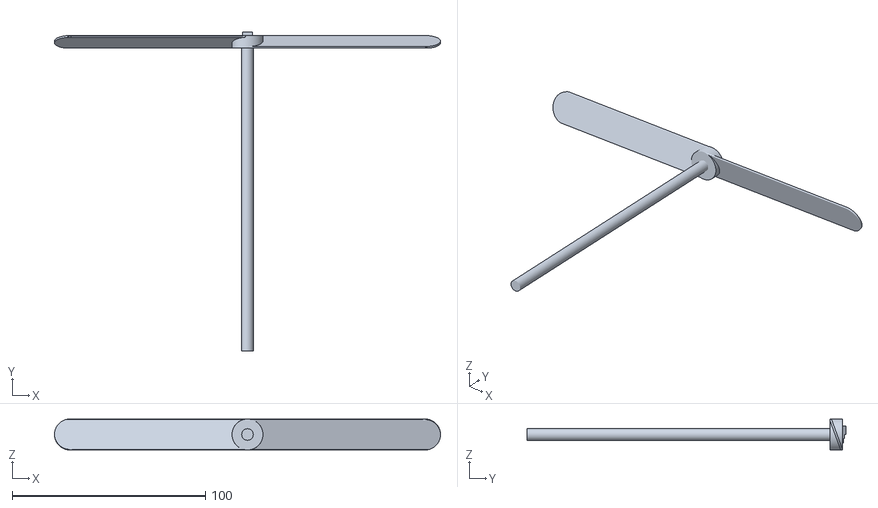
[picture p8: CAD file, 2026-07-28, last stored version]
Tab5 3D Render/input/Helicopter.stl
200.0 x 165.0 x 16.0

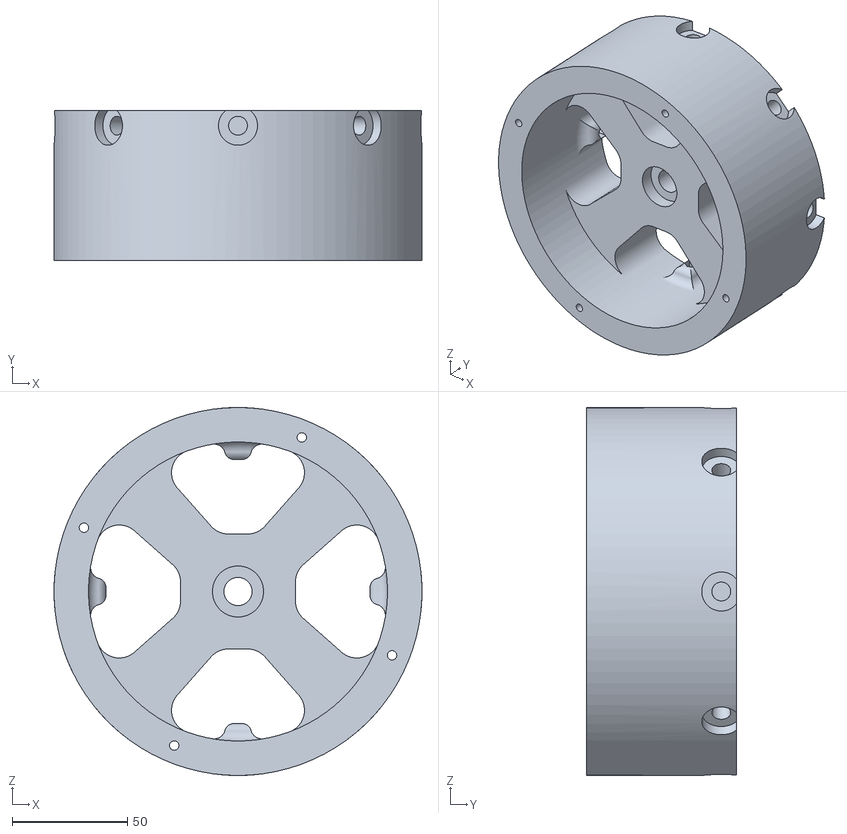
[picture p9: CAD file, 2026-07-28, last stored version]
Tab5 3D Render/input/1M2 Rotary plate.STL
160.0 x 65.0 x 160.0

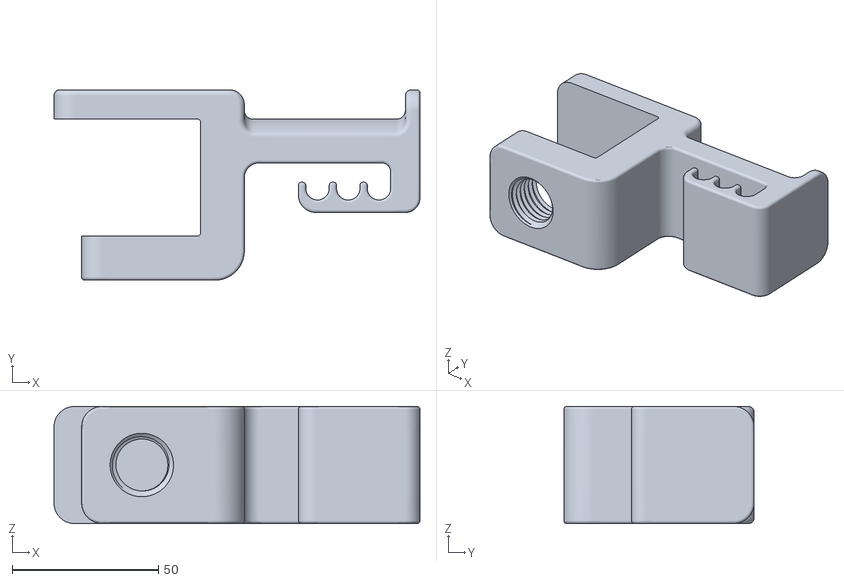
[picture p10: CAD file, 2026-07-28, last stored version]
Tab5 3D Render/input/Desk_Headphone_Holder_WIDE.stl
125.0 x 65.0 x 40.0

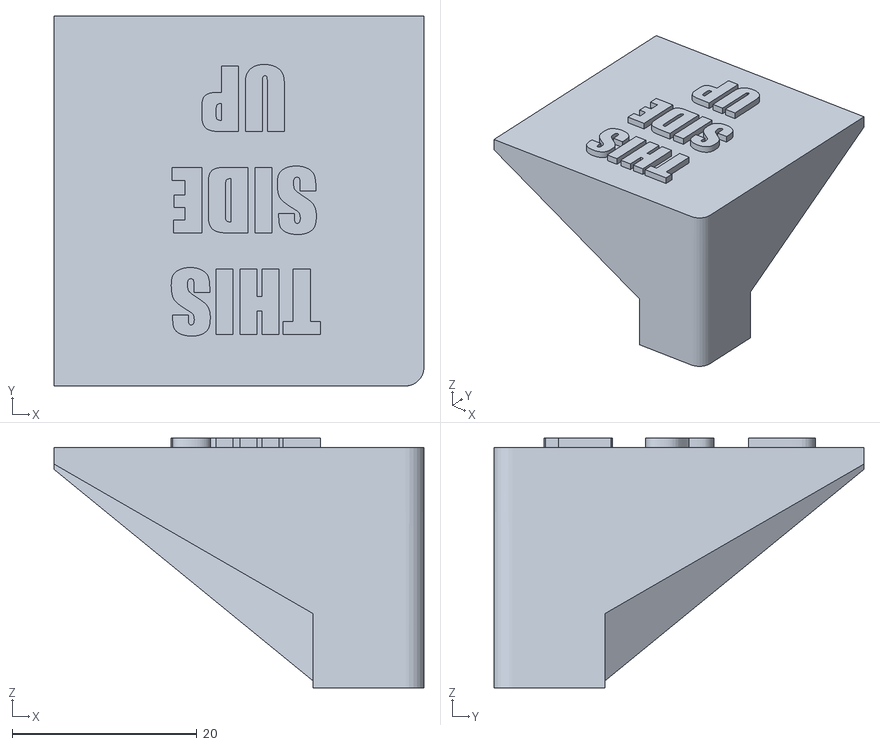
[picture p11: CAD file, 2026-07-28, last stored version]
Tab5 3D Render/input/advanced-bridge-calibration.stl
40.0 x 40.0 x 27.0

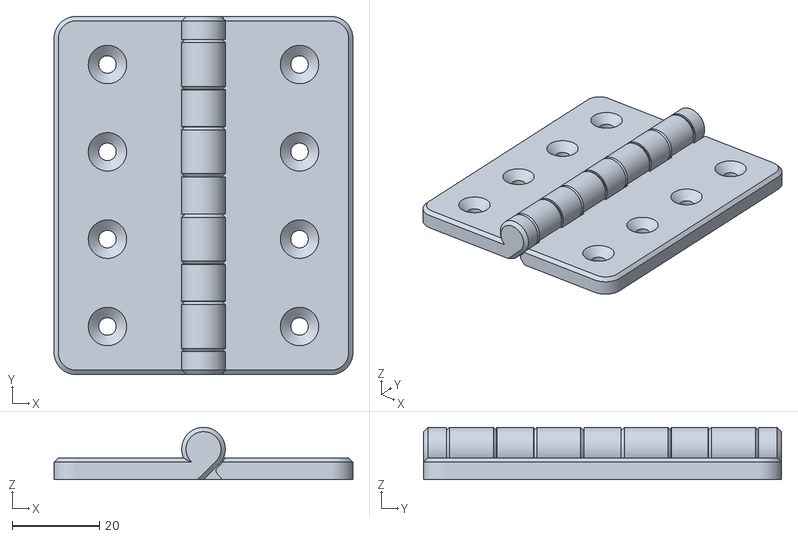
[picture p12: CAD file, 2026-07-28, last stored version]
Tab5 3D Render/input/hinge-4.stl
68.5 x 82.0 x 12.0

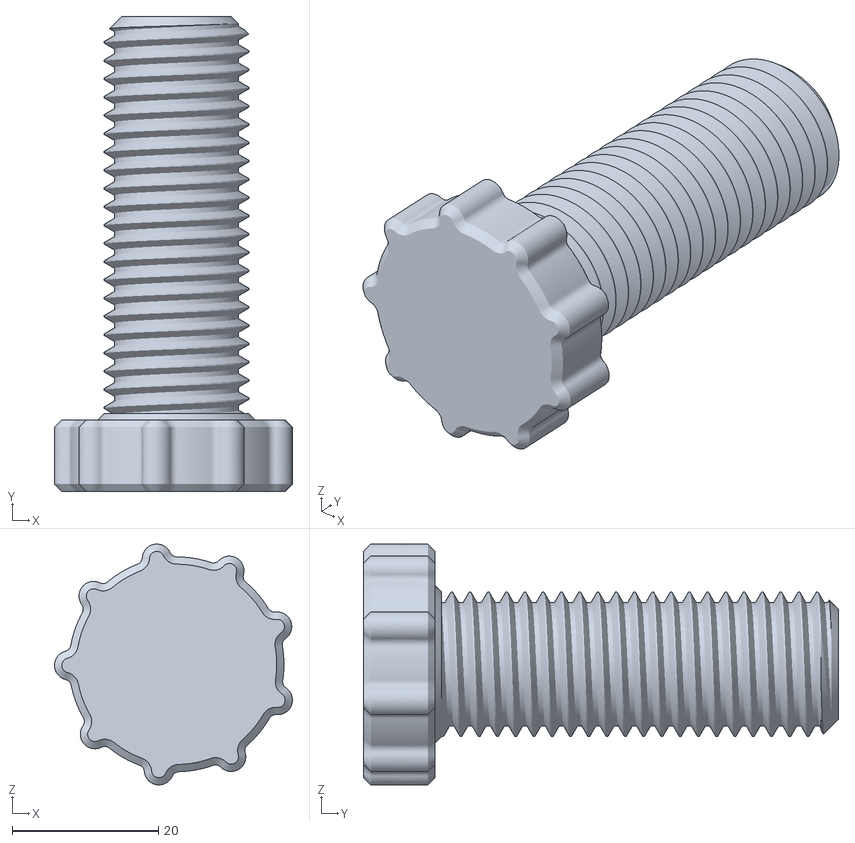
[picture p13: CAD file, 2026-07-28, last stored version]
Tab5 3D Render/input/Desk_Headphone_Holder_Screw_Long.stl
32.6 x 65.0 x 33.0

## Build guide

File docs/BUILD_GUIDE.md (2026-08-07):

# Build Guide — from parts to first scan

Everything to reproduce Project Platypus, in order. Nothing here assumes
prior M5Stack or PlatformIO experience; it does assume you can run commands
in a terminal.

**Difficulty:** Intermediate. There is no soldering and no fabrication —
assembly is cables and SD cards; the work is flashing two devices and one
config file. Budget an afternoon.

**The external antenna is optional.** Everything — scanning, surveys,
heatmaps — works with the Tab5's internal antenna alone. The external MMCX
port enables the *per-antenna comparison* layer (survey the same room on two
antennas and flip between heatmaps). Any 2.4GHz antenna with an MMCX pigtail
works there; ours is a self-designed patch PCB, but a $3 whip demonstrates
the feature identically.

---

## 0. Desktop prerequisites (before touching hardware)

Any OS works; commands below are shown for Windows PowerShell.

1. **Python 3.10+** — then:
   ```bash
   pip install pyserial pillow
   ```
   (`pyserial` drives flashing/telemetry tools, `pillow` the screenshot
   converter.)
2. **PlatformIO** — either the VS Code extension (easiest) or the CLI:
   ```bash
   pip install platformio
   ```
   The ESP32-P4 toolchain (pioarduino 54.03.21) downloads automatically on
   the first build. First build takes several minutes; later builds ~40s.
3. **USB serial drivers** — the Tab5 enumerates as a standard USB CDC device
   (no driver needed on Win10+/macOS/Linux). Note your COM port in Device
   Manager (ours shows as COM6 throughout the docs).
4. Clone the repo.

## 1. Hardware assembly (10 minutes)

1. **microSD into the Tab5** (FAT32, any size) — rooms, surveys, and
   settings live here.
2. **microSD into the Unit V** (FAT32, ≤32GB) — copy
   `meshscan/unitv/model/20class.kmodel` to the card root so it reads
   `/sd/20class.kmodel` on-device.
3. **Grove cable**: Unit V Grove port → the Tab5's Grove port (the HY2.0-4P
   next to the USB-C). This is the camera's data tether (UART, 460800).
4. Optional: **external antenna** onto the Tab5's MMCX RF connector.
5. Optional: battery / battery sled for untethered scanning.

Strain-relieve the Grove cable (a loop of tape works) — good practice on
any handheld rig with a moving tether.

## 2. Flash the Unit V camera (15 minutes)

The camera runs MaixPy **v0.5.0**. If your Unit V has different firmware,
install v0.5.0 first with kflash/kflash_gui (one-time; M5's docs cover it).

1. Plug the Unit V into USB (shows up as its own COM port — ours is COM10).
2. Build the single-file firmware bundle and upload it:
   ```bash
   cd meshscan/tools
   python unitv_bundle.py
   python unitv_upload.py ../unitv/build/boot.py /flash/boot.py COM10
   ```
3. Done. On boot the camera prints `[tele]`/`[det]` telemetry on its USB
   console (115200) while streaming to the Grove port — handy for sanity
   checks, not required for operation.

Why a bundle? This MaixPy build's boot-time filesystem imports are
unreliable, and `/sd` shadows `/flash` in its module path. One `boot.py`
executed from RAM sidesteps both classes of failure. Camera settings (baud,
model path, detection threshold, anchors) live in `meshscan/unitv/config.py`
— rebuild + re-upload after edits.

## 3. Configure + flash the Tab5 (20 minutes first time)

1. **Create your WiFi credentials header** (gitignored, never committed) at
   `Tab5 3D Render/include/wifi_creds.h`:
   ```cpp
   #pragma once
   #define OTA_WIFI_SSID  "your-network"
   #define OTA_WIFI_PASS  "your-password"
   #define OTA_HOSTNAME   "platypus-tab5"
   ```
   WiFi is used for OTA updates and the RF survey. (Without the file the
   build fails by design — there are no default credentials.)
2. **First flash is over USB.** Put the Tab5 in download mode — hold the
   power button until it enters the bootloader (the back-panel silkscreen
   documents the combos: HOLD = boot/download, double-press = on/off) —
   then:
   ```bash
   cd "Tab5 3D Render"
   pio run -e tab5 -t upload --upload-port COM6
   ```
3. **Known quirk:** after a USB flash the Tab5 often *stays* in download
   mode. Tap the power button once; you'll hear the boot beep and see the
   splash. (An `esptool --chip esp32p4 run` also works.)
4. **Every later flash can be over WiFi** — no cable, no download mode:
   ```bash
   pwsh tools/ota_push.ps1
   ```
   The device accepts OTA only while sitting on the home screen (green
   `OTA ready` chip, top right) — by design, so updates never fight the
   applets that use the radio.

## 4. First scan (5 minutes)

1. Power on → three tiles. Open **Room Scan**.
2. Tap **Scan new room**. Stand in a corner, face it, hold the tablet
   still — a tick sounds when the gyro is calibrated (~1s).
3. Sweep 360° at a comfortable pace, pointing the camera around the room.
   The ring fills as you turn; colored pips drop where objects are found.
   The scan finishes itself at a full turn.
4. The room appears as a 3D carved floor plan. Orbit with a finger,
   pinch to zoom. **OBJ** toggles detected objects; **SCAN+** / **WALK+**
   extend the room; **RF** starts a WiFi survey.
5. For the survey: pick your AP once (tap the AP row), then either walk the
   room during a **WALK+** (samples collect automatically at your position)
   or tap-your-position → **SAMPLE HERE** manually. The heatmap paints over
   the floor plan with a dBm legend and DEAD/BEST callouts; the **ANT**
   button flips between internal/external antenna layers.

## 5. Troubleshooting

| Symptom | Cause / fix |
|---|---|
| "SD card not found" on boot | Tab5 SD not seated; reinsert, restart |
| Scan shows no camera preview | Grove cable seated? Camera powered (LED)? Its USB console should show `[tele]` lines |
| Preview freezes seconds at a time, then recovers | Known intermittent: the link drops into a CRC-error window and the receiver resyncs itself within a few seconds. Root cause under investigation; continuing the sweep rides through it |
| Detections but empty rooms | Sweep slower; ensure the room is well-lit (the K210 is light-hungry); check `[scan] uart ... crcErr` stays low on the serial monitor |
| OTA "no response" | Device must be ON the home screen; same WiFi as your PC |
| Tab5 dark after USB flash | It's parked in download mode — tap power once (§3.3) |
| Serial monitor gibberish | Tab5 CDC needs DTR asserted: the bundled tools set it; PuTTY/minicom must too |

## 6. Optional: debug + capture tooling

- Pixel-perfect device screenshots over USB:
  ```bash
  python "Tab5 3D Render/tools/tab5_screenshot.py" COM6 shot.bmp
  ```
- Timed telemetry capture (what diagnosed the cable fault):
  ```bash
  python "Tab5 3D Render/tools/serial_log.py" COM6 300 run.log
  ```
- 1Hz health lines on the serial monitor: `[scan] uart frames/detects/
  crcErr/resync` during scans, `[hb] up/home/ota/heap` heartbeat always.

## 7. Where to go next

- **`docs/CODE_TOUR.md`** — a guided reading order for the source.
- **`docs/`** roadmap specs — ToF wall ranging, custom detection model.
- Camera tuning: `meshscan/unitv/config.py` + `Tab5 3D Render/docs/DETECTION_TUNING.md`.

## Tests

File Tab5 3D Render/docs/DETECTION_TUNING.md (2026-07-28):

# Detection Quality — Test Protocol & Roadmap

Current state: kendryte tiny-YOLOv2 VOC-20 (2018) on the Unit V KPU, threshold
0.15, inference every 3rd frame. It works (person/tvmonitor/bottle confirmed
live) but confidences run low (16–27%) and placement is coarse. This doc is
the plan to make detection *good*, ordered by evidence-per-hour.

## The instrument we already have
The camera prints `[det] fid=N: class=NN%` for every detection and `[tele]`
lines with fps — over the USB-C console (COM10), while the Grove keeps
feeding the Tab5. Every test below is "point camera at X, capture 30–60 s of
console, count". Claude can run capture + scoring scripted; the human moves
the camera. Keep lighting constant within a test.

## Tier 1 — characterize what we have (one evening, no code changes)

**T1. Class × distance profile.** For each class we care about (person, chair,
tvmonitor, bottle, sofa if available): hold the camera on the object at ~1 m,
~2 m, ~3 m for 30 s each. Metrics per cell: detection rate (dets/inference)
and mean confidence. Output: a table that tells us (a) each class's usable
range, (b) whether 0.15 is the right threshold per class, (c) which classes
are hopeless on this model.

**T2. False-positive census.** 60 s pointed at object-free wall/floor, 60 s at
a cluttered but known scene. Count spurious dets by class. This sets the
threshold floor: raise until FP rate ~0, check what recall survives (T1 data).
(Early signal: bottles may be over-firing — the "27 objects" scan.)

**T3. Lighting sensitivity.** T1's 2 m case repeated: lights on / off /
backlit. If confidence collapses when backlit, scan UX guidance ("lights on,
avoid windows behind objects") is a free accuracy win for the demo.

**Analysis is scripted:** parse `[det]` lines → rate + confidence stats per
run. (Tool candidate: `meshscan/tools/det_bench.py`, ~an hour to write when
T1 starts.)

## Tier 2 — cheap wins on current hardware

- **Per-class thresholds** (camera-side, config table): VOC classes differ
  wildly in calibration; T1/T2 give the numbers. 30-minute change.
- **Tab5 accumulator tuning** with T1 stats: merge radius (now 0.6 m),
  MIN_OBSERVATIONS (now 2), and weighting confident detections higher when
  averaging positions.
- **Exposure tuning** if T3 shows sensitivity: lock AGC ceiling / brightness
  in `sensor` init.
- **NOT worth it:** chasing the input-geometry theory further (the model
  demonstrably runs at 320×240), or hand-editing anchors.

## Tier 3 — the real jump: replace the model
The 2018 kendryte model is the ceiling. We are **kmodel V4 capable** now
(MaixPy v0.5.0), which opens:

1. **MaixHub pre-trained V4 detector** (~an afternoon). Modern training =
   better calibration; expect usable confidences at 0.4+ instead of 0.2.
   Swap = download → SD → update anchors/classes in config.py → rebundle.
2. **Custom-trained model on MaixHub** (~a weekend, the contest-grade move).
   Train on exactly the indoor classes Room Scan needs — including ones VOC
   lacks: **door, window, desk, shelf** (door alone transforms room
   understanding). MaixHub's train service outputs kmodel + anchors directly.
   Needs a labeled dataset: MaixHub public sets + ~100–300 photos of real
   rooms (the Tab5 demo rooms themselves — free training data from scans).
3. (Fallback if MaixHub friction: aXeleRate local training → nncase convert.)

## Recommended roadmap (contest-aware)
1. **T1 + T2 next camera session** (~1 hr) → per-class thresholds + Tab5
   tuning from data, not vibes. Immediate demo improvement.
2. **MaixHub V4 model swap attempt** right after — biggest win per hour.
3. **Custom model** only if the V4 zoo model underwhelms AND schedule allows
   before Aug 7; otherwise post-contest.
4. Placement accuracy beyond detection (multi-bearing triangulation of the
   same object across the sweep — we have yaw per observation now) is a
   post-contest Phase-2-adjacent project.

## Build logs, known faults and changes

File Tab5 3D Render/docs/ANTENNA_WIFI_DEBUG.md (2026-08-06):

# Antenna applet — WiFi crash debug (RESOLVED)

> **Update 2026-06-18/19:** WiFi fixed with `WiFi.setPins(12,13,11,10,9,8,15)`
> (Tab5 C6 hosted-SDIO pins) before WiFi init — verified on hardware. The
> RF-switch I²C issue below is also fixed in code: `expWrite/expRead` now use
> `M5.In_I2C` (the Tab5's internal bus, already initialised by `M5.begin()`)
> instead of raw un-begun `Wire`. INT/EXT switching awaits an on-device test.
> Original investigation kept below for reference.

Status as of 2026-06-16. Firmware is flashed and running on the Tab5 (COM6).
**3D Viewer + Room Scanner work.** The **Antenna applet crashes on launch** (blue
screen → reboot → back to M5View home).

## Root cause (confirmed from serial)

The app reaches `on_enter` (`[ANT] 1280x720`) then dies bringing up WiFi:

```
E sdmmc_common: sdmmc_init_ocr: send_op_cond (1) returned 0x107   (ESP_ERR_TIMEOUT)
E sdio_wrapper:  sdmmc_card_init failed
E H_SDIO_DRV:    sdio card init failed
FreeRTOS: Task "sdio_read" should not return, Aborting now!   → reboot
```

The ESP32-P4 has **no radio**; `WiFi.*` talks to the onboard **ESP32-C6 over an
esp-hosted SDIO link**. That link's init times out and the hosted driver aborts
the system. Cause: `platformio.ini` uses **`board = esp32-p4-evboard`** (generic
EVB) — the installed platform has **no M5Stack Tab5 profile** (only
`esp32-p4-evboard.json` / `esp32-p4.json`), so the C6 SDIO pins/sdkconfig don't
match the Tab5. The standalone Arduino sketch worked because the Arduino-IDE
M5Stack package ships the correct Tab5 config. **This is a build-config gap, not
an app bug.**

## Second, non-fatal issue
Just before the crash: `Wire.cpp: NULL TX buffer pointer` (repeated). The I²C bus
for the RF-switch expander (`0x43`) is never `begin()`'d under this build, so
INT/EXT antenna switching won't work even once WiFi is fixed. The standalone
sketch relied on `M5.begin()` setting up that bus. Fix: explicitly init the
correct Tab5 I²C bus (likely `Wire1`/`M5.In_I2C`) in `app_setup()`.

## Next session plan
1. Get the Tab5 C6 esp-hosted SDIO pin config. Fastest: **which board did the
   user select in the Arduino IDE** for the working antenna sketch (+ M5Stack
   board-package version)? That encodes the right pins/sdkconfig. Otherwise
   research M5Stack Tab5 C6 SDIO mapping.
2. Port that into `platformio.ini` as `build_flags` / sdkconfig overrides
   (esp_wifi_remote / esp_hosted SDIO pins), or switch to a real Tab5 board def
   if one becomes available.
3. Fix the RF-switch I²C bus init in the antenna applet.
4. Re-flash (remember `PYTHONIOENCODING=utf-8`), monitor, re-test Antenna.

## Note
SD is mounted via `SD_MMC` (SLOT 0) in `main.cpp`. Watch for SD ↔ C6 SDIO
interaction once WiFi config is corrected (may or may not be related).

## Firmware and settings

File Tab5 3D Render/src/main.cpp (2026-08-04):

// ============================================================
// main.cpp — M5View Shell Entry Point
// ============================================================

#define MESH_LOADER_IMPL
#define RENDERER_IMPL

#include <M5Unified.h>
#include <M5GFX.h>
#include <math.h>
#include <esp_heap_caps.h>
#include <SD_MMC.h>
#include <algorithm>

#include <WiFi.h>
#include <ArduinoOTA.h>
#include <esp_task_wdt.h>

#include "mesh.h"
#include "mesh_loader.h"
#include "renderer.h"
#include "applet.h"
#include "ui_constants.h"
#include "shell.h"
#include "viewer_applet.h"
#include "scanner/scanner_applet.h"
#include "antenna/antenna_applet.h"
#include "wifi_creds.h"          // gitignored: OTA_WIFI_SSID/PASS/HOSTNAME
#include "ui_feedback.h"
#include "ui_icons.h"

// The scan-finish path (mesh writer + geometry + SD + renderer frames deep in
// call chains) brushed the default 8KB Arduino loop stack — intermittent panic
// at scan completion. Give the loop task real headroom.
SET_LOOP_TASK_STACK_SIZE(16 * 1024);

static Shell shell;

// Boot splash. Drawn BEFORE the SD mount and applet construction so it fills
// startup time that already existed rather than adding any — the shell paints
// over it when it's ready. First frame the judges (and the demo video) see.
static void boot_splash() {
    int w = M5.Display.width(), h = M5.Display.height();
    M5.Display.fillScreen(COL_BG);
    ui_icons::radar(&M5.Display, w / 2, h / 2 - 96, 120, ui_theme::ACCENT);
    ui_theme::font_title(&M5.Display);
    M5.Display.setTextColor(ui_theme::TEXT, COL_BG);
    const char* t1 = "PROJECT PLATYPUS";
    M5.Display.setCursor(w / 2 - M5.Display.textWidth(t1) / 2, h / 2 + 10);
    M5.Display.print(t1);
    ui_theme::font_button(&M5.Display);
    M5.Display.setTextColor(ui_theme::ACCENT, COL_BG);
    const char* t2 = "Room Scanner  +  RF Survey";
    M5.Display.setCursor(w / 2 - M5.Display.textWidth(t2) / 2, h / 2 + 60);
    M5.Display.print(t2);
    ui_theme::font_mono1(&M5.Display);
    M5.Display.setTextColor(ui_theme::SUBTEXT, COL_BG);
    const char* t3 = "M5Stack Tab5 - ESP32-P4 - Unit V K210";
    M5.Display.setCursor(w / 2 - strlen(t3) * 3, h - 60);
    M5.Display.print(t3);
}

void setup() {
    Serial.begin(115200);
    // Brief settle only. This used to block up to 3s waiting for a USB host —
    // on battery that was 3 dead seconds on every power-on, in the demo.
    delay(300);
    Serial.println("\n=== M5View booting ===");

    auto cfg = M5.config();
    M5.begin(cfg);
    M5.Display.setRotation(1);
    M5.Display.fillScreen(TFT_BLACK);
    boot_splash();
    uint32_t splash_ms = millis();

    Serial.printf("Display: %dx%d\n",
                  M5.Display.width(), M5.Display.height());

    // SD card
    SD_MMC.setPins(12, 13, 11, 10, 9, 8);
    if (!SD_MMC.begin("/sdcard", false)) {
        Serial.println("SD mount FAILED");
        M5.Display.setTextColor(TFT_YELLOW);
        M5.Display.setTextSize(2);
        M5.Display.setCursor(10, 10);
        M5.Display.println("SD card not found");
        M5.Display.println("Insert SD and restart");
        delay(3000);
    } else {
        Serial.println("SD mounted OK");
    }

    // Register applets — Settings is panel-only, not a tile
    shell.register_applet(new ViewerApplet());
    shell.register_applet(new ScannerApplet());
    shell.register_applet(new AntennaApplet());
    // Future applets go here:
    // shell.register_applet(new NotesApplet());

    ui_feedback::begin();        // speaker up + boot beep (default volume)
    // Hold the splash to a legible minimum; SD mount + applet construction
    // above have usually eaten most of this already.
    while (millis() - splash_ms < 1100) delay(20);
    shell.begin(M5.Display.width(), M5.Display.height());   // applies saved volume/brightness
    Serial.println("M5View ready");
}

// ---- serial screenshot -------------------------------------
// PC sends the two bytes "SS" over USB-CDC; we reply
//   "SCRB" | u16 width | u16 height | width*height RGB565 (LE)
// streamed row by row (2.5KB buffer). tools/tab5_screenshot.py drives this
// and saves a PNG/BMP — pixel-perfect captures with no SD involved, works in
// every applet state.
static void serial_screenshot() {
    int w = M5.Display.width(), h = M5.Display.height();
    static uint16_t row[1280];
    if (w > 1280) w = 1280;
    Serial.write((const uint8_t*)"SCRB", 4);
    uint16_t dims[2] = { (uint16_t)w, (uint16_t)h };
    Serial.write((const uint8_t*)dims, 4);
    for (int y = 0; y < h; ++y) {
        M5.Display.readRect(0, y, w, 1, row);
        Serial.write((const uint8_t*)row, w * 2);
    }
    Serial.flush();
}

static void poll_serial_commands() {
    static uint8_t last = 0;
    while (Serial.available()) {
        uint8_t b = (uint8_t)Serial.read();
        if (last == 'S' && b == 'S') { serial_screenshot(); last = 0; }
        else last = b;
    }
}

// ---- WiFi OTA (home screen only) ---------------------------
// Cable-free flashing: `pio run -e tab5-ota -t upload`. Active ONLY while the
// shell sits on the home screen so it never fights the applets that manage
// WiFi themselves (antenna suite, RF survey). Leaving home tears the state
// down; returning re-joins and re-arms OTA. C6 SDIO pins are set once here.
// (PT_ prefix: ArduinoOTA.h already claims OTA_IDLE)
// LIFECYCLE RULE learned from a live freeze: ArduinoOTA/mDNS must be begun
// AT MOST ONCE per boot on the hosted-WiFi P4 — an end()/begin() cycle on
// applet exit/entry wedged the loop task inside the second begin(). So: join
// once, begin once, and applets merely pause handle(). If an applet tears
// WiFi down (antenna suite), OTA stays suspended until the next reboot
// rather than risking a re-init hang.
enum PtOtaState { PT_OTA_IDLE, PT_OTA_JOINING, PT_OTA_READY, PT_OTA_SUSPENDED };
static PtOtaState ota_state = PT_OTA_IDLE;
static uint32_t ota_join_start = 0;

static void ota_tick(bool at_home) {
    // Leaving home: applets own the radio. Dropping our STA association here
    // matters — the antenna suite's scans/RSSI scope fought the live OTA
    // connection ("OTA gets in the way on Antenna" field report). The
    // association is cheap to re-establish; ArduinoOTA itself is never
    // re-begun (hard-learned begin-once rule).
    static bool was_home = true;
    if (!at_home) {
        if (was_home && (ota_state == PT_OTA_JOINING || ota_state == PT_OTA_READY)) {
            WiFi.disconnect();
            ota_state = PT_OTA_SUSPENDED;
            Serial.println("[ota] suspended: applet owns the radio");
        }
        was_home = false;
        return;
    }
    was_home = true;
    switch (ota_state) {
    case PT_OTA_IDLE:
        WiFi.setPins(12, 13, 11, 10, 9, 8, 15);   // M5Tab5 C6 hosted-SDIO
        WiFi.mode(WIFI_STA);
        WiFi.begin(OTA_WIFI_SSID, OTA_WIFI_PASS);
        ota_join_start = millis();
        ota_state = PT_OTA_JOINING;
        break;
    case PT_OTA_JOINING:
        if (WiFi.status() == WL_CONNECTED) {
            ArduinoOTA.setHostname(OTA_HOSTNAME);
            ArduinoOTA.begin();                   // ONCE per boot, ever
            Serial.printf("[ota] ready: %s @ %s\n", OTA_HOSTNAME,
                          WiFi.localIP().toString().c_str());
            ota_state = PT_OTA_READY;
        } else if (millis() - ota_join_start > 20000) {
            ota_join_start = millis();            // keep retrying quietly
            WiFi.disconnect();
            WiFi.begin(OTA_WIFI_SSID, OTA_WIFI_PASS);
        }
        break;
    case PT_OTA_READY:
        if (WiFi.status() != WL_CONNECTED) {
            // an applet (or the AP) dropped the link; try to re-associate but
            // never re-run ArduinoOTA.begin()
            WiFi.begin(OTA_WIFI_SSID, OTA_WIFI_PASS);
            ota_state = PT_OTA_SUSPENDED;
            break;
        }
        ArduinoOTA.handle();
        break;
    case PT_OTA_SUSPENDED:
        // Back at home: quietly re-associate until the link returns, then
        // resume handling with the ORIGINAL ArduinoOTA instance.
        if (WiFi.status() == WL_CONNECTED) ota_state = PT_OTA_READY;
        else if (millis() - ota_join_start > 8000) {
            ota_join_start = millis();
            WiFi.begin(OTA_WIFI_SSID, OTA_WIFI_PASS);
        }
        break;
    }
}

// Home-screen status chip: WiFi/OTA state + IP, bottom-left. Redrawn on a
// slow tick because the shell repaints home whenever it goes dirty.
static void draw_status_chip(bool at_home) {
    static uint32_t last = 0;
    if (!at_home || millis() - last < 500) return;
    last = millis();
    int h = M5.Display.height();
    const char* txt; uint16_t col;
    switch (ota_state) {
        case PT_OTA_READY:     txt = nullptr;             col = 0x0300; break;
        case PT_OTA_JOINING:   txt = "WiFi: joining...";  col = 0x39E7; break;
        case PT_OTA_SUSPENDED: txt = "OTA: reconnecting"; col = 0x8200; break;
        default:               txt = "WiFi: off";         col = 0x39E7; break;
    }
    char buf[48];
    if (!txt) {
        snprintf(buf, sizeof(buf), "OTA ready  %s", WiFi.localIP().toString().c_str());
        txt = buf;
    }
    // Top-right of the header bar. It used to sit at the bottom, where it
    // overlapped the tiles — visible clutter in the first frame of the demo.
    (void)h;
    int w = M5.Display.width();
    M5.Display.fillRoundRect(w - 312, 17, 300, 26, 5, col);
    ui_icons::wifi(&M5.Display, w - 294, 30, 18, TFT_WHITE);
    M5.Display.setFont(&fonts::Font0);
    M5.Display.setTextSize(1);
    M5.Display.setTextColor(TFT_WHITE, col);
    M5.Display.setCursor(w - 278, 25);
    M5.Display.print(txt);
}

// Serial heartbeat: pinpoints where any future freeze happened (last line
// before silence) — 5s cadence keeps logs light.
static void heartbeat(bool at_home) {
    static uint32_t last = 0;
    if (millis() - last < 5000) return;
    last = millis();
    Serial.printf("[hb] up=%lus home=%d ota=%d heap=%u\n",
                  (unsigned long)(millis() / 1000), at_home ? 1 : 0,
                  (int)ota_state, (unsigned)ESP.getFreeHeap());
}

void loop() {
    // Task watchdog: a wedged loop now reboots with a WDT report after 60s
    // instead of hanging forever (a live lockup needed a manual power cycle).
    static bool wdt_armed = false;
    if (!wdt_armed) {
        esp_task_wdt_config_t wcfg = { .timeout_ms = 60000, .idle_core_mask = 0,
                                       .trigger_panic = true };
        esp_task_wdt_reconfigure(&wcfg);
        esp_task_wdt_add(NULL);
        wdt_armed = true;
    }
    esp_task_wdt_reset();

    bool at_home = !shell.is_in_applet();
    poll_serial_commands();
    ota_tick(at_home);
    heartbeat(at_home);
    shell.update();
    shell.render();
    draw_status_chip(at_home);
}

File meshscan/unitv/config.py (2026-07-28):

# config.py - MeshScan Unit V (K210 / MaixPy) configuration
#
# Keep this module import-light: it is loaded at boot before anything else.
# No numpy, no heavy stdlib. Plain constants only.

# ---- camera ---------------------------------------------------------------
# OV2640 on the Unit V. QVGA keeps JPEG small enough to stream at 115200 and
# matches what the depth estimator on the M5Tab assumes.
FRAME_WIDTH  = 320
FRAME_HEIGHT = 240

# Horizontal field of view of the OV2640 at this crop, in degrees. Used by the
# M5Tab depth/azimuth math, but kept here too so both ends share one number if
# you re-export. Measure yours and update — 60 deg is a reasonable default.
CAMERA_HFOV_DEG = 60.0

JPEG_QUALITY = 50        # 0..100; lower = smaller packets, blockier image.
                         # Real-room frames at 60 hit 13KB+, brushing the
                         # 460800-baud ceiling (~46KB/s); 50 buys fps headroom.

# Run KPU inference every Nth frame; intermediate frames re-send the last
# detections. Inference (~120ms) dominates the loop — every 3rd frame roughly
# triples stream fps while detection still updates ~1.7x/sec (scan samples 1/s).
DETECT_EVERY_N = 3

# ---- UART -----------------------------------------------------------------
# Start conservative. Bump to 1.5M or 3M once framing is proven stable.
UART_BAUD = 460800   # 4x of 115200. 921600 was too fast for the K210 UART. Tab5 must match.
UART_TX_PIN = 35         # Unit V grove pad -> M5Tab RX  (verify your wiring)
UART_RX_PIN = 34         # Unit V grove pad <- M5Tab TX

# ---- model ----------------------------------------------------------------
# Pascal VOC 20-class tiny-YOLOv2 (kmodel V3, works with this 2019 MaixPy).
# Put 20class.kmodel on the SD card root.
MODEL_PATH = "/sd/20class.kmodel"

# YOLOv2 detection layer parameters.
# DIAGNOSTIC: threshold dropped to 0.15 to establish whether the kendryte
# model emits ANYTHING under MaixPy (dets=0 mystery). If boxes appear at low
# confidence, raise back toward 0.4; if still zero, it's an input-geometry /
# model-compat issue and we switch to a MaixHub V4 model.
DETECT_THRESHOLD = 0.15  # min confidence to emit a detection
DETECT_NMS       = 0.3   # non-max-suppression IOU

# Anchors for the detection layer. These MUST match the anchors the .kmodel was
# trained with. These are the standard tiny-yolo-voc (20-class) anchors that the
# canonical 20class.kmodel uses. If your model differs, replace them.
ANCHORS = (1.08,  1.19,
           3.42,  4.41,
           6.63,  11.38,
           9.42,  5.11,
           16.62, 10.52)

# Pascal VOC 20-class names, index == class_id sent over UART. Order is the
# standard VOC order the 20class.kmodel was trained with — the M5Tab side
# (object_labels + depth_estimator) MUST use this same order.
CLASS_NAMES = (
    "aeroplane", "bicycle", "bird", "boat", "bottle",
    "bus", "car", "cat", "chair", "cow",
    "diningtable", "dog", "horse", "motorbike", "person",
    "pottedplant", "sheep", "sofa", "train", "tvmonitor",
)

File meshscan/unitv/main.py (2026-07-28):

# main.py - MeshScan Unit V entry point.
#
# Pipeline per loop iteration:
#   1. Capture a QVGA frame from the OV2640.
#   2. Run YOLOv2 on the KPU -> list of detections (empty if no model loaded).
#   3. JPEG-compress the frame.
#   4. Send a FRAME packet, then the paired DETECT packet, over UART.
#
# The M5Tab drives the experience (start/stop scan, orbit, save). The Unit V is
# a dumb sensor: it streams frame+detections continuously whenever powered.
# Launched by /flash/boot.py (the MeshScan launcher that replaces the StickV
# factory demo). Streams a live feed even with no detection model present.

import sensor
import image
import time
from machine import UART
from fpioa_manager import fm

import config
from detector import Detector
import uart_protocol as proto


def init_camera():
    # Sensor reset can fail the first few attempts on the Unit V — retry.
    for _ in range(20):
        try:
            sensor.reset()
            break
        except Exception:
            time.sleep_ms(100)
    sensor.set_pixformat(sensor.RGB565)      # KPU + JPEG both work from RGB565
    sensor.set_framesize(sensor.QVGA)        # 320x240
    sensor.set_hmirror(False)
    sensor.set_vflip(False)
    sensor.skip_frames(time=300)             # let AGC/AWB settle


def init_uart():
    # Map the grove pads to the UART2 peripheral.
    fm.register(config.UART_TX_PIN, fm.fpioa.UART2_TX, force=True)
    fm.register(config.UART_RX_PIN, fm.fpioa.UART2_RX, force=True)
    return UART(UART.UART2, config.UART_BAUD, 8, 0, 0, timeout=1000, read_buf_len=256)


def main():
    init_camera()
    uart = init_uart()
    detector = Detector()            # camera-only if no kmodel is present
    print("[main] streaming %dx%d @ %d baud, detect=%s" % (
        config.FRAME_WIDTH, config.FRAME_HEIGHT, config.UART_BAUD,
        "on" if detector.available else "off"))

    frame_id = 0
    clock = time.clock()
    detect_n = getattr(config, "DETECT_EVERY_N", 1)
    detections = []          # last inference result, re-sent between runs

    while True:
        clock.tick()
        img = sensor.snapshot()

        # 1) run inference every Nth frame only (it dominates loop time);
        #    intermediate frames carry the previous detections.
        if frame_id % detect_n == 0:
            detections = detector.detect(img)
            if detections:
                # loud detection telemetry: name what the model sees
                print("[det] fid=%d:" % frame_id, " ".join(
                    "%s=%d%%" % (config.CLASS_NAMES[d.class_id]
                                 if d.class_id < len(config.CLASS_NAMES)
                                 else str(d.class_id), d.confidence)
                    for d in detections[:5]))

        # 2) compress. img.compress() mutates into JPEG in place, so do it last.
        jpeg = img.compress(quality=config.JPEG_QUALITY)
        jpeg_bytes = jpeg.to_bytes()

        # 3) FRAME then paired DETECT, back to back
        uart.write(proto.pack_frame(jpeg_bytes))
        uart.write(proto.pack_detect(frame_id, (d.as_tuple() for d in detections)))

        frame_id = (frame_id + 1) & 0xFFFF

        # telemetry (console only): frame id, detections, fps, jpeg size
        if frame_id % 10 == 0:
            print("[tele] fid=%d objs=%d %.1ffps jpeg=%dB" % (
                frame_id, len(detections), clock.fps(), len(jpeg_bytes)))


main()

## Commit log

2026-07-28 Project Platypus: initial commit — M5View shell, Room Scan, RF Survey, Antenna
    Tab5 (ESP32-P4) firmware: applet shell hosting the 3D mesh viewer, Room Scan
    (Unit V K210 camera -> VOC-20 detection -> labeled 3D room meshes, IMU-yaw
    sweeps), RF Survey (per-antenna WiFi heatmaps on self-scanned floor plans),
    and the 2.4GHz antenna test suite. Plus Unit V MaixPy firmware (single-file
    bundle deploy), desktop tools (bundler, fast serial uploader, SD-shadow fix,
    serial screenshot), and the archived meshscan reference implementation.
    [1M2 Rotary plate.STL, 2M2H.STL, Desk_Headphone_Holder_Screw_Long.stl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]
2026-07-28 WiFi OTA flashing (home-screen-only ArduinoOTA) + tab5-ota env; first cable-free flash verified
2026-07-28 Fix loop freeze (OTA/mDNS begin-once lifecycle), add heartbeat, 60s task watchdog, home-screen OTA status chip
    [main.cpp]
2026-07-28 Additive multi-scan rooms + live viewfinder + room delete + unified smooth scrolling
    - Room object database (.objs sidecar, world coords): rescans register against
    existing objects (36-step yaw x pair-hypothesis search, translation from
    matched landmarks, identity fallback <2 matches) and merge observations, so
    rooms improve per walk instead of resetting. SCAN+ button in the 3D view.
    - LIVE VIEW: continuous detection viewfinder (~6fps, rotated 2x preview,
    class-colored boxes with upright name+confidence tags).
    - Long-press a room row -> delete confirmation (mesh + all sidecars).
    - Viewer file browser ported to the same pixel-smooth scroll as Room Scan
    (clip-rect partial rows, conti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
    [scanner_applet.h, viewer_applet.h]
2026-07-29 Speaker pseudo-haptics (tick/buzz on interactions) + fix lingering live-view name tags
    [scanner_applet.h, viewer_applet.h]
2026-07-31 Layout-first mapping (width-based ranging for wide furniture, big-object footprint), discerning detection display (conf floor + 2-frame persistence), detection boxes on scan preview, corner-origin hi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
    [scanner_applet.h]
2026-07-31 2x scan preview, display policy (layout+living shown, clutter hidden, plate contains all displayed), haptics KISS revert
    [scanner_applet.h]
2026-07-31 Origin arrow marker + 'start' label at scan origin (points toward the faced corner); plate always covers origin
2026-07-31 Add ShadowScan applet: silhouette -> polygon -> extruded STL
    Port of the standalone "UnitV Outline Capture" project into M5View.
    The Unit V keeps its existing MeshScan firmware — ShadowScan consumes
    the same FRAME JPEG stream on Serial1 and does all vision work on the
    P4: Otsu/manual threshold, border-majority polarity pick, largest
    4-connected component, Moore boundary trace, adaptive RDP simplify.
    Flow: LIVE preview/capture -> outline review (Chaikin smooth w/ undo,
    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
2026-07-31 Vibe pass v1: ui_theme (palette+FreeSans typography) + vector icons, press flashes, PLATYPUS wordmark; REAL settings: live volume+brightness sliders persisted to SD; sound tuning (2.5kHz tick, master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
2026-07-31 Settings slider fix (targeted row repaint, no ghost/haze; 800Hz preview pip), sweep-dial scan screen (progress ring + detection pips at discovery bearings)
    [scanner_applet.h]
2026-07-31 Detection calibration + per-room object on/off menu + room list declutter (HELD: not flashed)
    - Calibration: accumulate only detections passing the display gate
    (conf floor + 2-frame persistence) - one-frame ghosts no longer earn
    map markers ("finding a little too much" root cause)
    - OBJ menu in room view: every confirmed object gets a row with ON/off
    pill; toggles persist in .objs (ROB2, flags byte; ROB1 read-compat)
    and rebuild the mesh, plate re-fits to whats shown; hidden-by-default
    clutter (bottles) can now be turned ON per room
    - listRooms filters to .mesh only - .lbl/.objs/.rf sidecars no longer
    appear as phantom rooms in the browse list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
    [scanner_applet.h]
2026-08-01 Yaw deadband (2 dps): pitching the camera no longer creeps sweep progress
    [scanner_applet.h]
2026-08-01 Ranging hardening (HELD): median positioning + box sanity gates
    - Accumulator: component-wise median of first 9 samples per object
    replaces running mean - one bad range no longer drags a marker
    - estimate(): reject tiny boxes (<8px ranging dimension), edge-clipped
    boxes fall back to height ranging (truncated width read as "farther"),
    aspect-ratio sanity for known-width classes, 8m indoor range ceiling
    [scanner_applet.h]
2026-08-01 ToF wall-ranging research: Tab5 M5-Bus exposes internal I2C (G31/G32), ToF4M rides it at 0x29 - no Grove conflict; sampling math, pipeline, enclosure notes
2026-08-01 Scan fixes from field test: stillness-locked gyro bias + accumulation gate rollback
    - Bias calibration now requires a genuinely still 900ms window (any
    disturbance restarts it; tick sounds when locked). Motion during the
    old fixed window became "zero" and the ring ran on its own - the
    "sweep went waaaay too fast" bug
    - Map accumulation: consecutive-frame persistence was too strict for a
    16-27% model at ~2 detect fps (empty scans); now ACC_CONF=18 floor
    only - spatial confirmation via MIN_OBSERVATIONS does the vetting.
    Display boxes keep the strict 2-frame gate
    [scanner_applet.h]
2026-08-01 Visibility-carved floors (non-rectangular rooms) + person-class strictness; ToF/enclosure to post-contest roadmap
    - Floor is now the occupancy union of origin + objects + sight-line
    corridors (0.25m grid, run-merged slabs): L-shapes and extensions
    emerge from camera evidence instead of one bounding rectangle
    - VOC "person" (the trigger-happiest class) needs conf>=25 and 4+
    sightings vs 18/2 for furniture - fixes a scan mapping half a room
    as people
    - TOF_RANGING.md marked post-contest (hardware + enclosure deferred)
    [scanner_applet.h]
2026-08-02 Fix empty OBJ menu: _open_room now loads the .objs sidecar
    The object DB was only loaded on SCAN+, so opening a room after a
    reboot left RAM empty (blank OBJ menu) - and stale DB contents from a
    previously scanned room could leak into another rooms menu/rebuild.
    Also: an empty DB can never rebuild (wipe) an existing mesh.
    [scanner_applet.h]
2026-08-02 Floor: greedy rect cover, top-only (no underside bleed). Settings: instant open/close (trail root cause) + state-aware applet repair
    - addFloorCells: greedy maximal-rectangle top surface, bottom faces
    removed - slab undersides tied with tops in the painter sort and bled
    through as dark streaks; large unified quads kill the plank seams
    - Settings panel: slide animation removed. Closing revealed strips
    nothing repainted (ghost titles/dividers around applet canvases -
    screenshot-confirmed). Instant open/close, one clean draw each way
    - ScannerApplet::on_resume repairs per state: VIEW/LIVE clear+redraw,
    SCAN redraws chrome (extracted _draw_scan_chrome, arc/preview reset)
    Co-Authored-B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
    [scanner_applet.h]
2026-08-02 Walk scanning (#2), building map (#4), RF dead-zone/best-spot callouts (#5)
    - Walk scan: PoseTracker (IMU step detection -> dead-reckoned pose),
    detections placed from the walked pose, path recorded as floor-truth
    carve evidence (.path sidecar, PTH1), live path mini-map on the scan
    screen, FINISH-only exit (no 360 target)
    - room_carve.h: shared visibility-carve (origin + path + objects +
    sight-lines from nearest path anchor) used by mesh rebuild AND map
    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
2026-08-02 Contest build: 3-tile shell, boot splash, heatmap legend, faster startup
    Repo split: this is now the CONTEST repo. Development, ShadowScan, and
    post-contest work live in the private platypus-lab repo.
    - ShadowScan removed from the shell (not part of the submission story;
    a 4th tile dilutes the demo). Full source preserved in platypus-lab.
    - Home is now 3 full-height tiles: Viewer / Room Scan / Antenna
    - Boot splash drawn before SD mount + applet construction, so it fills
    startup time that already existed instead of adding any
    - Startup no longer blocks up to 3s waiting for a USB host (dead time on
    every battery power-on, including on camera)
    - RF heatmap: signal-strength legend with d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
    [main.cpp, scanner_applet.h]
2026-08-02 Add ota_push.ps1: reliable one-command OTA that bypasses the broken package path
    pio run -e tab5-ota -t upload now dies inside PlatformIO package management
    ("VCS: Unknown repository type tool-riscv32-esp-elf-gdb" - it misreads the
    symlink:// toolchain workaround). Building is unaffected, so build with pio
    and hand the .bin straight to espota.py. Includes a failure checklist; the
    usual cause is the device sitting inside an applet rather than home.
2026-08-02 Walk is additive-only: WALK+ on an open room; scan-frame path registration fix
    Design: a sweep ESTABLISHES a room (origin + landmark constellation,
    360 auto-finish); a walk EXTENDS one (floor truth, missed objects).
    Walking a brand-new room had no landmarks to register against, so
    dead-reckoning drift went uncorrected - removed from BROWSE (back to
    Scan | Live | Building map). Room view now offers WALK+ beside SCAN+.
    Bug fix found during the rewire: an additive walks path points are in
    the SCAN frame (walk starts at "0,0" wherever you stand) but only the
    objects received the registration transform - the paths new points now
    get the identical transform before merging/persisting. Mini-map dra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
    [scanner_applet.h]
2026-08-02 Sweep calibration: ACC_CONF 18->16, ASPECT_TOL 1.8->2.2 (sweeps were missing real furniture); walk merge radius 1.1m + 600ms sampling; OTA drops STA association when leaving home (antenna suite owns 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
    [main.cpp, scanner_applet.h]
2026-08-02 +15% sweep sensitivity: ACC_CONF 14 (floor = camera threshold), MIN_BOX_PX 7, ASPECT_TOL 2.5, MAX_RANGE 9m
2026-08-03 Doc day plan (Aug 3) + Hackster writeup draft (paste-ready, [SLOT]-marked)
2026-08-03 Review fixes: deleteRoom removes .path sidecar (recycled names inherited dead walk trails); building.map name buffers zeroed before write
    [scanner_applet.h]
2026-08-03 Directional antenna: every RF sample records its bearing (RFS3)
    The survey stored RSSI as a scalar field over position - correct for the
    omni internal antenna, wrong for a patch, whose RSSI depends on aim as
    much as location (10-15dB front-to-back). Two samples from one spot
    facing different ways were being IDW-averaged into mush.
    - Sample.heading (deg, 0 = mesh +Z, -1 unknown); RFS2 files still load
    - Survey runs the IMU and asks you to face the START arrow on entry,
    which ties the survey heading frame to the room frame
    - Aim whisker on every sample dot; live bearing readout in the panel
    - UI states the procedure: patch = AIM AT AP, omni = aim irrelevant
    - AP direction estimate: ray from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
    [scanner_applet.h]
2026-08-04 Walk-fused RF survey: one walk maps the room and the WiFi (RFS4)
    WALK+ now doubles as a survey. If a target AP is known, WiFi comes up,
    the RF switch follows the selected antenna, and every 1.5s a single
    single-channel scan (60ms dwell, ~100ms block - under the IMU tick
    staleness guard, ~7% duty) records the AP at the current pose AND
    bearing. The walk mini-map drops a signal-coloured dot per sample, so
    the heatmap builds itself as you walk. No AP configured -> skipped
    silently, walk unchanged.
    Also fixes a real pre-existing bug found while tracing coordinates:
    .rf samples live in quantised mesh space, and ANY rebuild that changed
    the rooms bounds (OBJ menu hiding an object, a WALK+/SCAN+ t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
    [scanner_applet.h]
2026-08-05 WALK+/SCAN+ calibration prompt: "Hold still a moment" - the corner ritual belongs to a rooms first sweep only; additive scans start anywhere (registration finds the frame). Prompt was telling walkers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
2026-08-06 Freeze log analysis: CRC-storm windows are link-side (self-recovering); fix cluster fragmentation (ACC_CONF 16, sweep merge 0.8m); quiet .path remove
    5-min serial capture caught a freeze live: frames stalled 4s while
    crcErr kept climbing - bytes arriving corrupt, then resync recovers.
    Loop alive throughout (it was counting the bad bytes). Prime suspect
    is the Grove cable/connector under strain on the new rig; "sweep
    faster to unfreeze" = arm movement reflexing the connector.
    Same capture exposed the sensitivity overshoot: "17 objects, 0
    confirmed" - conf-14 junk boxes jitter-scattered repeat sightings
    past the 0.6m merge radius, so nothing clustered. Floor back to 16,
    sweep merge radius to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
    [scanner_applet.h]
2026-08-06 Contest repo cleanup: cut 50MB of fluff, rewrite front door
    Pre-cleanup tip is pushed to platypus-lab (everything removed here is
    one checkout away there).
    CUT: personal STL collection + batch conversions (37MB), vendor K210
    firmware blobs (10MB), the abandoned ESP32-S3/LVGL scaffold
    (meshscan/m5tab - a second parallel codebase with a duplicate cv/ tree
    that made the real one look copy-pasted), internal process docs (demo
    script, doc-day plan, Hackster draft -> local notes/, gitignored),
    raw crash log (postmortem doc stays), dead sources (settings_applet.h,
    input.h), stale build helpers, duplicate sample meshes, old roadmap svg,
    PHASE_1.1 planning doc, .vscode.
    REWRITTEN: README.md - front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
    [1M2 Rotary plate.STL, 2M2H.STL, Desk_Headphone_Holder_Screw_Long.stl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]
2026-08-06 Reproduction docs: BUILD_GUIDE (prereqs -> assembly -> flash -> first scan + troubleshooting) and CODE_TOUR (guided reading order); antenna marked optional
    With instructions the build is Intermediate, not Advanced: no soldering,
    no fabrication - cables, SD cards, two flashes, one config file. The
    external antenna is optional (any MMCX antenna demos the per-antenna
    layer; the survey works on the internal antenna alone).
2026-08-06 README: the educational frame - ~$110 accidental RF classroom (make an antenna, measure it on your own map)
2026-08-07 Antenna suite culled to what demos: Oscilloscope + Walk Test (INT/EXT + CSV)
    Field call: the other seven screens (channel scan, polar, timeline,
    multipath, A/B dwell, polarisation, packet loss) never worked reliably
    and their GUIs were messy. Menu is now two big clean tiles; culled
    screen code remains compiled but unreachable for post-contest revival.
    README claims updated to match. Real antenna economics added: the
    custom patch fab run was $40 for 45 boards (~$0.90 each) - the antenna
    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
2026-08-07 Roadmap: M5-Bus expansion backbone (shared internal I2C -> ToF 0x29, joystick 0x63, Design B breakout PCB) + enclosure peripheral bay
2026-08-07 Retract cable-strain attribution for the camera freeze (reseat test falsified it)
    Docs now state only what telemetry proved: corrupt bytes arrive during
    the window, receiver stays healthy, resync self-recovers in seconds.
    Root cause marked under investigation. (Also ruled out today: the
    UART_MAX_JPEG cap is 24KB, well above observed 5-8KB frames.)
2026-08-08 Screenshot assets: splash, room view, OBJ menu, RF INT/EXT pair (AP ray + callouts), building map (12 rooms), antenna menu, scope INT/EXT A/B (+1.5dB)
2026-08-08 Sweep dial captures: hero frame (82%, 13 pips) + early-sweep frame (live detection box)
2026-08-08 System wiring schematic (Hackster schematics asset)
2026-08-08 Realistic rooms v1: carve smoothing + waist-high boundary walls; ToF sensor deep-dive doc
    - room_carve: two-pass majority filter after stamping - lone spurs erode,
    notches fill. Disc-scalloped amoeba outlines become clean runs while the
    evidence-driven shape survives. Shared by mesh + building map thumbnails.
    - addFloorCells: boundary edges extrude into 0.45m walls (both faces -
    renderer backface-culls and rooms are viewed inside and out). Floors
    finally read as ROOMS, not plates.
    - docs/TOF_SENSORS.md: how dToF works (SPAD histograms, VCSEL, why range
    accuracy survives dark targets), VL53L1X specifics (ROI steering, timing
    budgets, distance modes), ranked failure modes for wall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
